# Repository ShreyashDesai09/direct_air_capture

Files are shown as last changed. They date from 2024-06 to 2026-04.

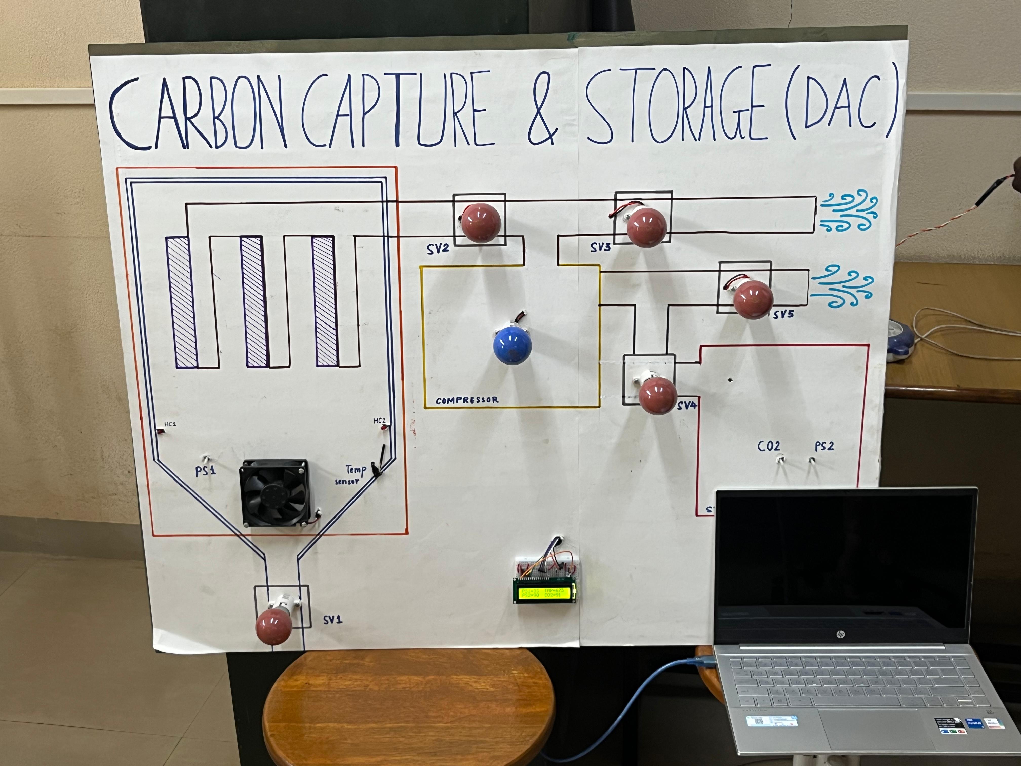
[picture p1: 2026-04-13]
Documents/Project.jpg

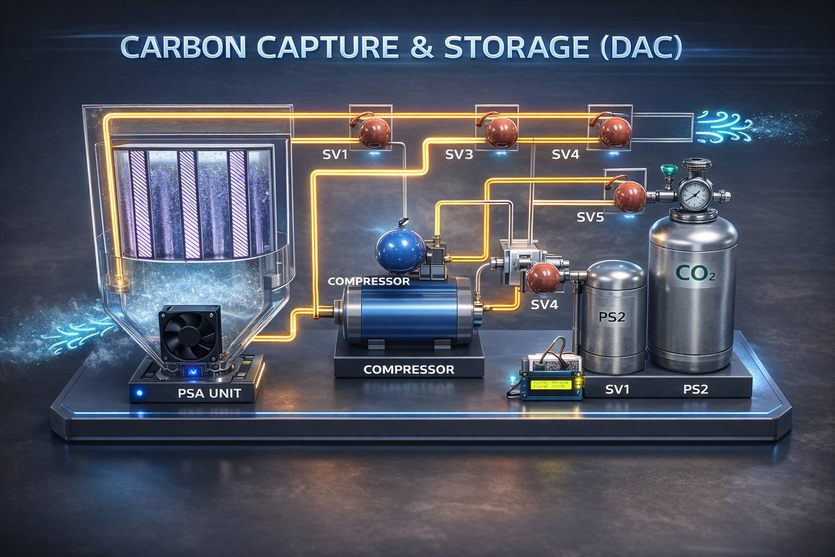
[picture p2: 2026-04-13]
Documents/Carbon Capture And Storage.png

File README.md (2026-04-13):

# Direct Air Capture Using Carbon Capture and Storage (CCS) technology

Arduino-based direct air capture system for extracting CO₂ from ambient air and storing it in a tank.  
🚀 A prototype showing hardware control, sensor monitoring, gas capture logic, and CAD-supported enclosure design.

Prototype schematic or mockup

## Project Summary

This repository contains the main Arduino sketch and supporting design assets for a direct air capture prototype. The system uses pressure, temperature, and CO₂ sensors to manage air flow, vacuum, heating, and storage stages.

The project demonstrates:

- 🧠 embedded Arduino control logic
- 🧪 analog sensor monitoring and serial debugging
- 💨 actuator control for fans, valves, heater, and vacuum
- 🛠️ CAD-based hardware design and assembly planning
- 📁 documentation-ready structure for prototyping

## What the System Does

- 🌡️ reads pressure, temperature, CO₂, and chamber pressure sensors
- 🌀 controls air flow, vacuum creation, heating, and storage
- 🧾 routes captured air through the sorbent/collection assembly
- 📡 displays live values on a 16x2 LCD and sends telemetry over Serial

## Key Files

- `Mega_Project_Final_Code.ino` — main Arduino sketch
- `README.md` — project overview and usage guide
- `Documents/3D Design/` — CAD parts for the sorbent panel and assembly

## Hardware Components

Typical components used in this prototype:

- 🧠 Arduino board (Uno, Nano, Mega, etc.)
- 🌿 CO₂ sensor module connected to `A2`
- 🧪 pressure sensors on `A0` and `A3`
- 🌡️ temperature sensor on `A1`
- 💨 fan or pump driver on pin `23`
- 🔧 solenoid valves `SV1`–`SV5` on pins `27`, `31`, `35`, `39`, `43`
- 🔋 vacuum compressor driver on pin `47`
- 🔌 heater control on pin `29`
- 🖥️ 16x2 LCD display wired via `LiquidCrystal` pins

## System Workflow

1. ⚙️ `setup()` initializes the LCD, serial port, sensors, and actuators.
2. 🔄 `loop()` cycles through:
   - `dis()` — read sensors and update LCD/Serial
   - `Air_Flow()` — open flow path and circulate air
   - `vacuum()` — close valves and engage vacuum
   - `heat()` — heat the chamber and monitor temperature
   - `store()` — manage final pressurization and storage
3. 🧭 Control decisions are based on measured analog values and safety thresholds.

## Operational Stages

- `Air_Flow()` — configures valves and fan to direct air through capture assembly
- `vacuum()` — closes flow valves, starts compressor, and creates negative pressure
- `heat()` — powers heater while monitoring temperature
- `store()` — manages final storage flow and chamber pressure

## 3D Design Assets

The `Documents/3D Design/` folder contains CAD files for the mechanical parts of the prototype, including:

- `sorbent panel.IGS`
- `I-section of sorbent panel.IGS`
- `100mm.CATPart`
- `150mm.CATPart`
- `left.CATPart`
- `right.CATPart`
- `Part1.CATPart`

These files can be used to visualize or manufacture the capture assembly and support structure.

## How to Use

1. 📝 Open `Mega_Project_Final_Code.ino` in Arduino IDE.
2. 🔌 Connect the Arduino to your PC.
3. 🔧 Wire the sensors and actuators according to the pin assignments in the sketch.
4. 🖥️ Select the correct board and COM port.
5. 📤 Upload the sketch.
6. 📟 Open Serial Monitor at `9600` baud and watch the LCD for live data.

## Recommended Enhancements

To make the project stronger and more portfolio-ready:

- 📊 add actual sensor mapping and calibration formulas
- 🧾 document the exact wiring and pin mapping
- 🧰 include a bill of materials (BOM)
- 📐 add a wiring diagram or schematic image
- 🎥 include photos or a demo video of the prototype
- 💾 add data logging or SD card export

## Notes

- ✅ Verify sensor wiring before powering the system.
- ⚠️ Calibrate the CO₂ sensor and temperature probe for accurate readings.
- 🔌 Ensure safe power, valve, and heater connections.

## License

This project is available for learning and experimentation. Add a license file if you want to define reuse terms explicitly.

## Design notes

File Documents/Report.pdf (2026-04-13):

A

Report on

## “Carbon Capture & Storage using Direct Air Capture Technology”

Submitted to

Shivaji University, Kolhapur

In Partial Fulfillment of therequirement for the degree of

Final Year of B. Tech

(ELECTRONIC AND TELECOMMUNICATION ENGINEERING)

Submitted by

PRN | Name of Student
2021000347 | Mr. Vaibhav Ramesh Kashid
2021000722 | Miss. Bhoomy Durgesh Lingras
2021000732 | Mr. Shreyash Amrut Desai
2122010119 | Mr. Archit Raghavendra Kulkarni

Under the guidance of

### Prof. A.R. Nigavekar

Submitted at

KOLHAPUR INSTITUTE OF TECHNOLOGY’S COLLEGE OFENGINEERING (AUTONOMOUS), KOLHAPUR

Year 2023-24

## CERTIFICATE

This is to certify that Mr. Vaibhav Ramesh Kashid (2021000347), Miss. Bhoomy Durgesh

Lingras (2021000722), Mr. Shreyash Amrut Desai (2021000732), Mr. Archit

Raghavendra Kulkarni (2122010119) have completed the Project Part-I on subject entitled

“Carbon Capture & Storage using Direct Air Capture Technology”, in the fulfillment of the

requirement for the award of Final Year (Electronics and Telecommunication Engineering) of

KIT’sCollege of Engineering, Kolhapur in the academic year 2023-24.

Date:

Place: Kolhapur

Prof. A.R. Nigavekar | External Examiner | Prof. Y. M. Patil
Project Guide | | Head ETC

Dr. M. B. Vanarotti

Director

## DECLARATION

We hereby declare that the Project entitled, “Carbon Capture & Storage using Direct Air Capture Technology” Phase-II project report submitted to KIT’s College of Engineering, Kolhapur, Maharashtra, INDIA in the partial fulfilment of the requirement for the “Electronics & Telecommunication” is a bona fide work carried out by us. The material contained in this Project has not been submitted to any University or Institution for the award of any degree.

Name of the Students:

Roll No. | Name | PRN No. | Signature
37 | Vaibhav Ramesh Kashid | 2021000347
38 | Bhoomy Durgesh Lingras | 2021000722
39 | Shreyash Amrut Desai | 2021000732
40 | Archit Raghavendra Kulkarni | 2122010119

Date:

Place: Kolhapur

## ACKNOWLEDGMENT

We would like to express our deep gratitude towards Prof. A.R. Nigavekarand Dr. Y.M. Patil

Head of Department for their constant encouragement and guidance. Their support and

cooperation throughout the project work has been ofimmense help to us.

We express our sincere thanks to all the teaching and non-teaching staff and all those who

have directly or indirectly helped in making the project a success.

PRN No. | Name of Student
2021000347 | Mr. Vaibhav Ramesh Kashid
2021000722 | Miss. Bhoomy Durgesh Lingras
2021000732 | Mr. Shreyash Amrut Desai
2122010119 | Mr. Archit Raghavendra Kulkarni

# Contents

6.3.2. Explanation of the Design Considerations for Efficiency, Scalability, and Cost-Effectiveness ...... 18

### 1. ABSTRACT

Addressing the pressing global challenge of rising atmospheric carbon dioxide

(CO2) levels demands innovative solutions to achieve climate stability. Current

reduction efforts fall short of meeting necessary targets, underscoring the urgency

for effective interventions. Direct Air Capture (DAC) technology emerges as a

promising avenue, yet it grapples with hurdles related to cost, energy efficiency,

and scalability. The crux of this mega project involves optimizing room-scale

DAC technology through an open-source framework, leveraging crowd-sourced

ideas, and a collaborative open data set for iterative enhancements. With a keen

understanding of the potential consequences of unchecked CO2 levels, the

overarching objective is to elevate carbon dioxide capture efficiency, champion

sustainability, and decisively combat climate change. This mega project stands

poised to catalyze transformative advancements, galvanizing collective efforts

toward a more sustainable future.

### 2. INTRODUCTION

### 2.1. CCS Technology:

Carbon Capture and Storage (CCS) is a critical technology aimed at reducing greenhouse gas

emissions, particularly carbon dioxide (CO2), from industrial processes and power generation. The

Intergovernmental Panel on Climate Change (IPCC) highlights CCS as one of the key strategies to

limit global warming to well below 2°C. The process involves capturing CO2 emissionsfrom

point sources such as power plants or industrial facilities, transporting it to storage sites, and

securely storing it underground in geological formations, preventing it from entering the

atmosphere and contributing to climate change.

### 2.2. Background and Significance of Carbon Capture & Storage:

The concept of CCS has gained significant attention in recent decades due to theurgent need to

mitigate climate change and reduce CO2 emissions. The burning of fossil fuels for energy

production is a major contributor to CO2 emissions,and CCS offers a way to capture and store

this CO2 before it reaches the atmosphere. By preventing CO2 emissions from entering the

atmosphere, CCScan help to achieve climate targets and transition to a low-carbon economy while

maintaining reliable energy supplies from fossil fuels during the transitionperiod.

### 2.3. Overview of Direct Air Capture (DAC) Technology:

Direct Air Capture (DAC) technology is an innovative approach to capturing CO2 directly from the

atmosphere, regardless of the source of emissions. Unlike traditional CCS, which captures CO2

from point sources, DAC systems can be deployed anywhere, making them versatile and scalable.

DAC technology typically involves large-scale chemical processes or sorbent materials that

selectively capture CO2 from ambient air. Once captured, the CO2 can be stored underground or

utilized in various industrial processes, such as enhanced oil recovery or production of synthetic

fuels.

### 2.4. DAC Importance:

DAC technology plays a crucial role in complementing traditional CCS methods by offering a

means to address emissions from sources that are difficult to capture, such as transportation and

agriculture. It provides a pathway to achieve negative emissions, where more CO2 is removed from

the atmosphere than emitted, helping to offset remaining emissions from sectors that are

challenging to decarbonize. DAC can also be integrated with renewable energy sources to create

carbon-negative energy systems, further reducing the carbon footprint of human activities.

### 2.5. Project Objectives:

The primary objective of this project is to investigate the feasibility and effectiveness of Direct Air

Capture (DAC) technology for carbon capture and storage (CCS) applications. Specifically, the

project aims to:

- Assess the technical and economic viability of DAC systems for capturing CO2 from the

atmosphere.

- Develop and optimize a DAC system prototype or model for carbon capture.
- Evaluate the environmental benefits and potential scalability of DAC technology for mitigating

climate change.

- Explore potential challenges and opportunities associated with the implementation of DAC

technology at scale.

- Provide recommendations for policy-makers, industry stakeholders, andresearchers on the role of

DAC in achieving climate goals and transitioning to a low-carbon future.

### 3. REVIEW OF LITERATURE

- By referring to paper [1], we understood about a technology assessment of DAC with a

focus on the chemical processes involved. It discusses the feasibility and challenges

associated with DAC technology.

- By referring to paper [2], we understood that this study explores the optimization of a

specific DAC system utilizing a two-loop hydroxide carbonate process. It discusses

improvements in efficiency and performance through countercurrent air flow.

- By referring to this research article [3], we got to know the transition of DAC technology

from laboratory-scale experiments to demonstration projects. It highlights advancements

made in scaling up DAC systems.

- After going through this review paper [4], we got to know the relevance of CCS

technologies, including DAC, in mitigating CO2 emissions. It addresses the challenges and

opportunities specific to the Indian context.

- The review presented in reference [5] provides an overview of various CO2 capture

technologies, including DAC, highlighting their challenges and potential solutions. It

discusses the technical aspects and economic considerations of CCS.

- After referring to the article of reference [6], we understood the cost implications of CCS

technologies, including DAC, emphasizing the importance of cost reduction strategies for

widespread deployment. It discusses factors influencing the cost of CO2 capture and

storage.

- By referring to this article [7], we got to know the state-of-the-art DAC technologies,

their mechanisms, and potential applications. It explores the scientific and engineering

aspects of DAC.

- By referring to paper [8], we understood about different solvents used for CO2absorption

from flue gas, a process relevant to DAC technology. It discusses the properties and

performance of various solvents and their implications for CO2 capture efficiency.

### 3.1. Review of Existing Literature on CCS and DAC Technology

Carbon Capture and Storage (CCS) and Direct Air Capture (DAC) technologies have gained

significant attention in recent years due to their potential to mitigate carbon dioxide (CO2)

emissions and combat climate change. A thorough review ofexisting literature reveals a wealth of

research papers, journals, and reports focusedon various aspects of CCS and DAC technology.

Numerous studies have explored the technical feasibility, economic viability, and environmental

implications of CCS and DAC implementations. These investigations encompass a wide range of

topics, including capture technologies, storage methods, cost analyses, policy frameworks, and

environmental impacts.

### 3.2. Summary of Key Findings

Key findings from relevant literature emphasize the following points:

1. Technical Feasibility: Research indicates that both CCS and DAC technologies are technically

feasible for capturing CO2 emissions from various sources, including industrial processes and

the atmosphere. Advances in capture techniques, such as solvent-based absorption and solid

adsorption, have demonstrated high CO2 capture efficiencies.

2. Economic Viability: While CCS and DAC technologies have historically faced economic

challenges, recent studies suggest that cost reductions are achievable through technological

innovation, scale-up, and policy support. Cost analyses highlight the importance of considering

factors such as energy requirements, capital investments, and operational expenses in

evaluating the economic feasibility of CCS and DAC projects.

3. Environmental Implications: Assessments of the environmental impacts associated with CCS

and DAC implementations underscore the importance of lifecycle assessments and

sustainability considerations. While CCS offers the potential to reduce CO2 emissions from

stationary sources, concerns exist regarding leakage risks and the long-term integrity of storage

reservoirs. Similarly, DAC technologies raise questions about energy consumption, land use,

and the potential for unintended environmentalconsequences.

4. Policy and Regulatory Frameworks: The development of supportive policy frameworks and

regulatory incentives is identified as a crucial enabler for the deployment of CCS and DAC

technologies at scale. Initiatives such as carbon pricing mechanisms, tax credits, and research

funding play significant roles in driving innovation and investment in carbon capture and

storage initiatives.

### 3.3. Discussion on the Current State of DAC Technology, Challenges, and

Opportunities

Despite significant progress in research and development, several challenges persist in the

advancement and widespread adoption of DAC technology:

1. Energy Intensity: DAC technologies currently exhibit high energy requirements, primarily

due to the need for air circulation, CO2 capture, and regeneration processes. Addressing the

energy intensity of DAC systems is critical to improving efficiency and reducing operational

costs.

### 2. Cost Competitiveness: While cost reductions have been achieved in recent years, DAC

remains more expensive than conventional carbon abatement strategies such as emission

reductions and renewable energy deployment. Enhancing cost competitiveness through

technological innovation and economies of scale is essential to unlocking the full potential of

DAC as a climate mitigation tool.

### 3. Scale-Up and Deployment: Scaling up DAC technology from laboratory prototypes to

commercial-scale installations presents logistical and infrastructural challenges. Deploying

DAC facilities at the necessary scale requires significant investment, infrastructure

development, and regulatory approvals.

4. Carbon Utilization and Storage: Utilizing captured CO2 for beneficial purposes, such as

enhanced oil recovery or the production of synthetic fuels, can enhance the economic viability

of DAC projects. However, ensuring the permanent and secure storage of captured CO2

remains a critical consideration for long-term carbon management.

Despite these challenges, DAC technology offers several opportunities for addressing global

carbon emissions:

1. Negative Emissions: DAC provides a pathway for achieving negative emissions by actively

removing CO2 from the atmosphere. Integrating DAC with carbon utilization and storage

strategies can enable net-negative emissions, helping to offset residual emissions from hard-to-

abate sectors.

2. Flexibility and Location Independence: Unlike traditional carbon capture technologies,

DAC systems are not limited by the proximity of emission sources, offering flexibility in

deployment and location independence. This characteristic makes DAC particularly suitable

for capturing emissions from dispersed sources and addressing CO2 emissions from sectors such as aviation and agriculture.

3. Technological Innovation: Continued research and development efforts are driving

technological innovation in DAC, leading to efficiency improvements, cost reductions, and

novel capture approaches. Advances in materials science, engineering design, and process

optimization hold promise for further enhancing the performance and scalability of DAC

systems.

4. Climate Resilience: DAC technology offers potential benefits for climate resilience by

providing a means to actively remove CO2 from the atmosphere, thereby helping to mitigate

the impacts of climate change. As part of a comprehensive climate mitigation strategy, DAC

can contribute to achieving ambitious emissions reduction targets and safeguarding vulnerable

ecosystems.

### 4. Problem Definition

Addressing the critical threat posed by rising atmospheric carbondioxide (CO2) levels to

global climate stability requires an innovative approach. Current efforts to reduce CO2

emissions fall short, necessitating the optimization of Direct Air Capture (DAC)

technology. However, DAC faces challenges in cost-effectiveness, energy efficiency, and

scalability. The goal is to improve room-scale DAC systems through an open-source

approach, using crowd-sourced ideas and open data for iterative enhancements. By

boosting CO2 capture efficiency, this initiative aims to promote sustainability and combat

climate change effectively. The focus is on collaborative innovation to refine DAC

technology for a more resilient and eco-friendly future.

### 5. Methodology

The objective of this project is to design, develop, and implement an innovative Direct Air Capture (DAC) system that addresses the urgent need for scalable and sustainable carbon removal solutions. This project aims to contribute to the mitigation of climate change by achieving the following key objectives:

### 5.1. Development of an Efficient DAC Technology:

- Design and construct a state-of-the-art DAC system that maximizes CO2 capture efficiency while minimizing energy consumption.
- Investigate and integrate advanced capture materials and methods, such as chemical sorbents, adsorption technologies,and electrochemical approaches, to enhance DAC systemperformance.

### 5.2. Scalability and Cost Reduction:

- Engineer the DAC system with scalability in mind, ensuring it can be deployed at a sizeable capacity to have a meaningful impact on CO2 removal.
- Explore innovative engineering and manufacturing processes to reduce the overall cost of DAC technology, making it economically viable for widespread deployment.

### 5.3. Carbon Utilization and Storage:

- Investigate opportunities for the utilization of captured CO2, such as in the production of carbon-neutral fuels, construction materials, or other value-added products.
- Implement effective and environmentally responsible strategies for the secure and long-term storage of captured CO2, including geologic storage and utilization in carbon-negative applications.

### 5.4. Environmental Sustainability:

- Conduct a comprehensive life cycle assessment (LCA) to evaluate the environmental footprint of the DAC system, taking into account emissions associated with construction, operation, and decommissioning.
- Develop strategies to minimize water usage, land footprint, and other potential environmental impacts associated with DAC deployment.

### 6. System Design

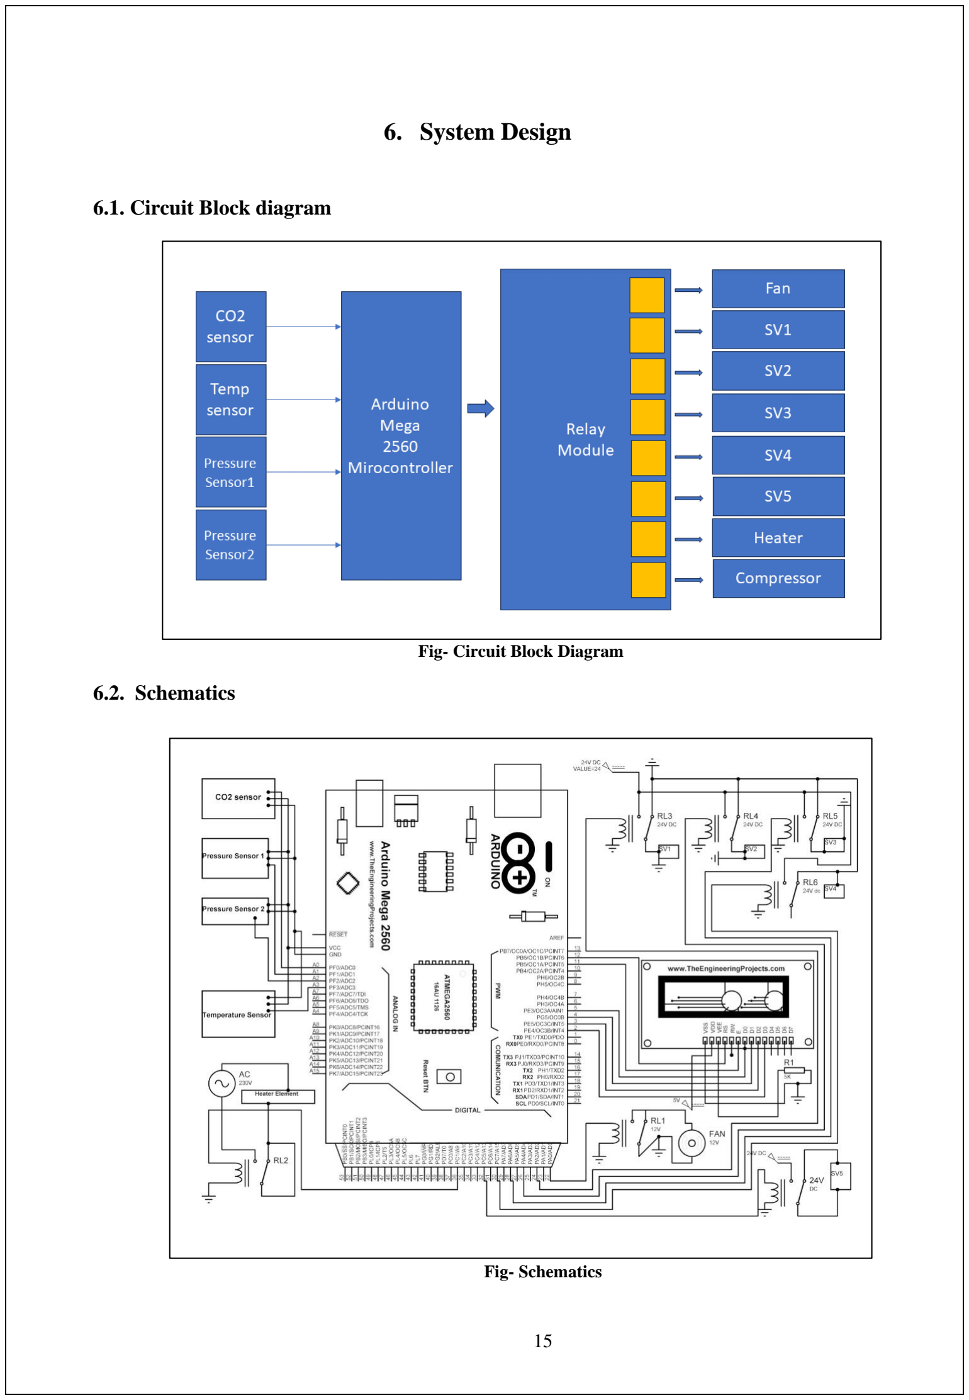
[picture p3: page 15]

### 6.1. Circuit Block diagram

Fig- Circuit Block Diagram

### 6.2. Schematics

Fig- Schematics

### 6.3. DAC System, Including Components and Subsystems

The Direct Air Capture (DAC) system is designed to capture carbon dioxide (CO2) directly from the

atmosphere using a combination of capture, separation, and storage processes. The system comprises

several key components and subsystems, each playing a critical role in the overall functionality and

performance of the DAC system:

- Air Intake System: The DAC system begins with an air intake system responsible for drawing ambient air into the capture unit. This system typically consists of intake vents or fans to facilitate the flow of air into the capture chamber.
- Capture Chamber: The capture chamber is the primary component where CO2 is captured from the ambient air. Various capture technologies can be employed, including chemical absorption, adsorption onto solid sorbents, or membrane separation. The choice of capture technology depends on factors such as efficiency, selectivity, and scalability.
- CO2 Separation Unit: Following capture, the CO2 must be separated from the capture medium for storage or utilization. Separation processes may involve desorption, regeneration, or purification steps to isolate the captured CO2 from the capture medium. Common separation techniques include thermal regeneration, pressure swing adsorption, or cryogenic distillation.
- CO2 Storage and Utilization: The separated CO2 can be stored underground in geological formations, utilized for enhanced oil recovery, or converted into valuable products such as synthetic fuels or building materials. The design of the storage and utilization subsystems depends on the intended application and regulatory requirements.
- Energy and Heat Management: The DAC system requires energy inputs for air circulation, capture, separation, and regeneration processes. Efficient energy management strategies, such as heat recovery, process integration, and renewable energy integration, are essential for minimizing energy consumption and enhancing system efficiency.
- Monitoring and Control System: To ensure optimal performance and operational safety, the DAC system incorporates monitoring and control systems for real-time monitoring of key parameters, process optimization, and fault detection. Sensors, actuators, and control algorithms are deployed to maintain system stability and reliability.

### 6.3.1. Main Block Diagram

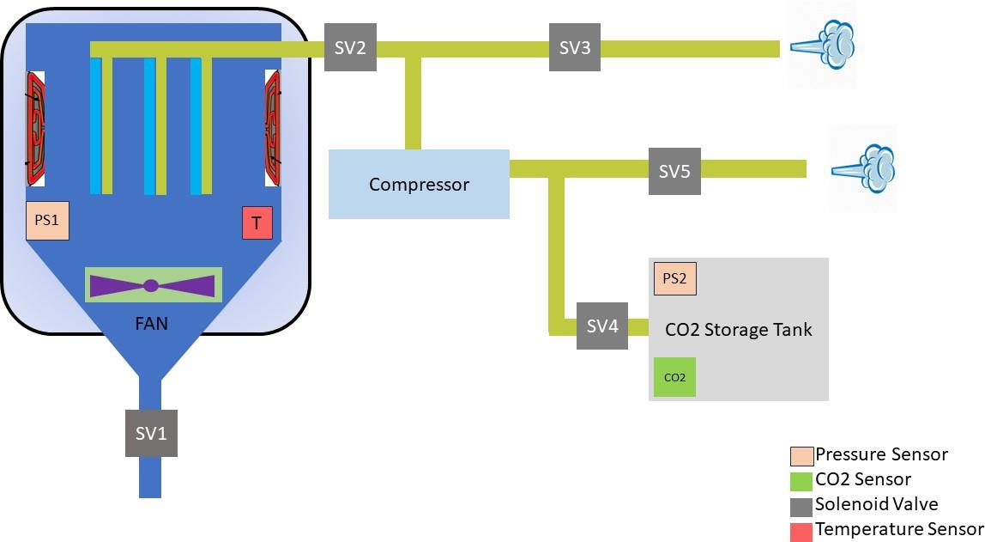
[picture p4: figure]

Fig. Carbon Capture and Storage using DAC Technology

The operation of the DAC system can be illustrated through schematic diagrams or flowcharts,

outlining the sequence of processes and interactions between system components. A simplified

flowchart of the DAC system operation include the following steps:

1. Air Intake: Ambient air is drawn into the capture chamber through intake vents or fans.
2. CO2 Capture: CO2 is captured from the incoming air using a capture medium or technology (e.g., chemical absorption, adsorption).
3. CO2 Separation: The captured CO2 is separated from the capture mediumthrough desorption or regeneration processes.
4. Storage/Utilization: The separated CO2 is either stored underground or utilized for various applications such as enhanced oil recovery or synthetic fuel production.

### 5. Energy Management: Energy inputs are managed efficiently to power the operation of the

DAC system, with considerations for energy recovery andrenewable energy integration.

6. Monitoring and Control: The system is monitored in real-time, and controlalgorithms adjust operating parameters to optimize performance and ensure safe operation.

### 6.3.2. Explanation of the Design Considerations for Efficiency, Scalability, and Cost-

Effectiveness

Efficiency, scalability, and cost-effectiveness are critical design considerations forthe DAC system:

1. Efficiency: The efficiency of the DAC system is influenced by factors such as capture efficiency,

energy consumption, and process integration. Design considerations focus on optimizing capture and

separation processes, minimizing energy requirements, and maximizing the utilization of captured

CO2.

2. Scalability: The scalability of the DAC system is essential for deploying large-scale installations

capable of capturing significant quantities of CO2. Design considerations include modularization,

equipment sizing, and process optimization to facilitate the expansion of the system while

maintaining performance and reliability.

3. Cost-Effectiveness: Achieving cost-effectiveness involves balancing capital investments, operational

expenses, and lifecycle costs. Design considerations include the selection of cost-competitive

materials and technologies, process optimization for resource efficiency, and the integration of

renewable energy sources to reduce operating costs.

### 7. Hardware and Software Required

### 7.1 HARDWARE

### 1. Microcontroller Board: -

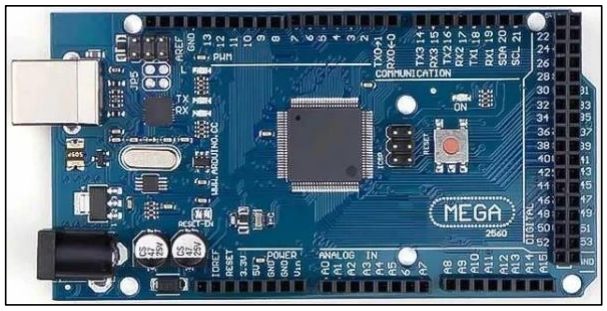
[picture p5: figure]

The Arduino Mega microcontroller board was chosen due to several key reasons:

- Extensive I/O Capabilities: The Arduino Mega offers a large number of digital and analog

input/output pins, making it suitable for connecting and controlling multiple sensors,

actuators, and peripherals simultaneously. This is crucial for a project like DAC technology,

which may involve numerous sensors for environmental monitoring, data acquisition, and

control purposes.

- Processing Power: With its ATmega2560 processor running at 16 MHz and ample flash

memory (256 KB), the Arduino Mega provides sufficient processing power and storage

capacity to handle complex algorithms, data processing tasks, and control logic required in

DAC systems. This is important for real-time monitoring, control, and decision-making

processes within the system.

- Compatibility and Community Support: Arduino boards, including the Mega, benefit from

a vast community of developers, makers, and enthusiasts. This ensures a wide range of

compatible libraries, example codes, tutorials, and community forums where you can seek

assistance, share ideas, and troubleshoot issues encountered during the project. This support

network can significantly expedite development and reduce implementation challenges.

- Expandability and Modularity: The Arduino Mega's modular design allows for easy

expansion through shields and modules, providing flexibility to add additional functionality

or interface with external devices as needed for your DAC technology project. This

scalability is advantageous for future upgrades or modifications to the system.

- Cost-Effectiveness: Compared to some other microcontroller boards with similar

capabilities, the Arduino Mega offers a balance of features, performance, and affordability.

This makes it a cost-effective choice for projects with demanding I/O requirements and

processing tasks, such as Direct Air Capture technology development.

Specifications:

- Microcontroller: ATmega2560
- Operating Voltage: 5V
- Input Voltage (recommended): 7-12V
- Input Voltage (limits): 6-20V
- Digital I/O Pins: 54 (of which 15 provide PWM output)
- Analog Input Pins: 16
- DC Current per I/O Pin: 20 mA
- DC Current for 3.3V Pin: 50 mA
- Flash Memory: 256 KB (8 KB used by bootloader)
- SRAM: 8 KB
- EEPROM: 4 KB
- Clock Speed: 16 MHz

### 2. Pressure Sensor: -

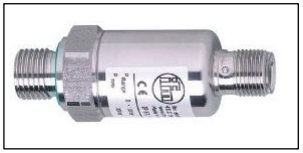
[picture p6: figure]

The PT9544 pressure sensor is used due to its suitability for measuring pressure in the context of

atmospheric conditions and vacuum systems.

- Pressure Range: The PT9544 sensor is designed to measure a wide pressure range, typically

from atmospheric pressure down to vacuum levels. This range is relevant for DAC

technology, where pressure measurements may span from ambient air pressure to lower

pressures within the capture and storage systems.

- Accuracy and Precision: The PT9544 sensor offers good accuracy and precision in pressure

measurements, which is essential for capturing reliable data in DAC processes. Accurate

pressure readings are crucial for monitoring and controlling the operation of air capture units,

ensuring optimal performance and efficiency.

- Compact and Versatile: The compact size of the PT9544 sensor makes it easy to integrate

into your DAC system without occupying excessive space. Its versatility allows for flexible

installation options, enabling precise pressure measurements at key points within the capture

and storage infrastructure.

- Reliability and Durability: The PT9544 sensor is designed for reliable long-term

performance, with features that enhance durability in varying environmental conditions. This

reliability is crucial for continuous and accurate pressure monitoring in DAC systems,

contributing to the overall effectiveness and stability of the technology.

Specifications:

- Pressure Range: Typically, 0 to 10 bar (other pressure ranges may be available)
- Output Signal: Analog (0-10V or 4-20 mA) (±0.5% of Full Scale (FS))
- Supply Voltage: 10-30 VDC
- Operating Temperature: -25°C to 85°C
- Electrical Connection: M12 connector or cable
- Material: Stainless steel (housing)

- Protection Rating: IP65/IP67 (depending on the variant)

### 3. CO2 Sensor: -

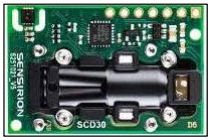
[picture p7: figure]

The Sensirion Non-Dispersive Infrared (NDIR) CO2 sensor was selected for several compelling

reasons:

- Accurate CO2 Measurement: NDIR sensors are known for their high accuracy in

measuring CO2 concentrations. This is critical in DAC systems, where precise monitoring of

CO2 levels in the air is essential for capturing and storing carbon dioxide effectively.

- Wide Measurement Range: The Sensirion NDIR CO2 sensor typically offers a wide

measurement range, allowing it to accurately detect CO2 concentrations ranging from

ambient levels to higher concentrations encountered in DAC processes.

- Stability and Long-Term Performance: NDIR technology provides stable and reliable CO2

measurements over extended periods, making it suitable for continuous monitoring and

control applications in DAC systems. Consistent performance is vital for maintaining the

efficiency and effectiveness of CO2 capture and storage processes.

- Low Power Consumption: Many NDIR CO2 sensors, including those from Sensirion, are

designed to operate with low power consumption. This is advantageous for energy-efficient

operation, especially in remote or off-grid DAC installations where power conservation is a

priority.

Specifications:

- Measurement Principle: Non-Dispersive Infrared (NDIR)
- Carbon Dioxide (CO2) Measurement Range: 0-40,000 parts per million (ppm)
- Accuracy: ± (30 ppm + 3% of measured value) within 400-10,000 ppm
- Response Time: <2 minutes (for 63% step change)
- Temperature Range (Operating): 0°C to 50°C
- Humidity Range (Operating): 0% to 100% RH (non-condensing)
- Supply Voltage: 3.3 V to 5.5 V
- Communication Interface: I2C (up to 400 kHz) and UART (up to 115200 bps)

- Dimensions: 35.6 mm x 23.3 mm x 3 mm (L x W x H)
- Digital Output Resolution: 16-bit
- Power Consumption (Average): 19 mA @ 3.3 V (continuous operation)
- Warm-up Time: <30 seconds

### 4. Molecular Sieves: -

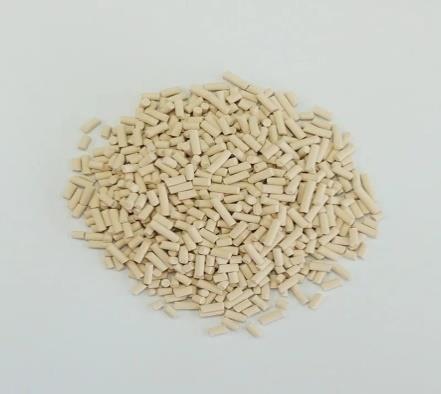
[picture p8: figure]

Molecular sieves specifically 13X taken into consideration due to its various abilities.

- Selective Adsorption: Molecular sieves are designed to selectively adsorb molecules of

specific sizes. 13X sieves are known for their ability to selectively adsorb CO2 from air while

allowing other gases like nitrogen and oxygen to pass through.

- High Capacity: 13X molecular sieves have a high CO2 adsorption capacity, meaning they

can capture a significant amount of CO2 per unit weight or volume of the sieves. This high

capacity is crucial for efficient DAC systems.

- Regenerability: Molecular sieves can be regenerated by desorbing the captured CO2,

allowing them to be reused multiple times. This makes them cost-effective and

environmentally friendly compared to single-use adsorbents.

- Stability: 13X molecular sieves are stable under a wide range of operating conditions,

including varying temperatures and pressures commonly encountered in DAC systems.

- Commercial Availability: These sieves are commercially available in large quantities,

making them readily accessible for DAC projects at scale.

Specifications:

- Type: 13X (Type X) molecular sieves
- Pellet Diameter: 1.6 mm (other diameters may also be available)
- Adsorbate: Primarily used for adsorption of CO2 from air

- Pore Size: Approximately 10 angstroms (1 nanometer), suitable for capturing CO2

molecules while allowing smaller molecules like nitrogen and oxygen to pass through

- Surface Area: Typically ranges from 600 to 800 square meters per gram (m²/g), providing

a large surface area for CO2 adsorption

- Adsorption Capacity: Can adsorb a significant amount of CO2 per unit weight of

molecular sieves, depending on the specific conditions and activation level

### 5. Temperature sensor: -

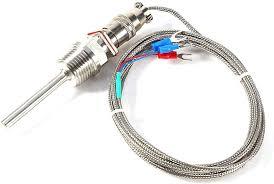
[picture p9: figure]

PT100 sensors, also known as platinum resistance temperature detectors (RTDs), are commonly

used in projects involving Direct Air Capture (DAC) technology for several reasons:

- Accuracy: PT100 sensors offer high accuracy in temperature measurement, which is crucial

for monitoring and controlling temperature-sensitive processes in DAC systems. Precise

temperature control is often necessary for optimal performance and efficiency.

- Stability: PT100 sensors are known for their stability and low drift over time. This ensures

that temperature measurements remain reliable and consistent throughout the operation of the

DAC system, leading to consistent process performance.

- Linear Response: PT100 sensors exhibit a linear response to temperature changes, making it

easier to calibrate and interpret temperature readings accurately. This linear response is

beneficial for maintaining specific temperature setpoints in DAC processes.

- Wide Temperature Range: PT100 sensors can operate in a wide temperature range,

including the elevated temperatures that may be encountered in DAC systems during certain

processes like CO2 desorption or regeneration of adsorbents.

- Compatibility: PT100 sensors are compatible with standard measurement and control

systems commonly used in industrial settings, making integration into DAC technology

projects relatively straightforward.

- Industry Standard: PT100 sensors are widely used and well-established in various

industries for temperature sensing applications due to their accuracy, stability, and reliability.

This makes them a preferred choice for many DAC technology projects where precise

temperature control and monitoring are essential.

Specifications:

The specifications of a PT100 temperature sensor, which is a type of platinum resistance

temperature detector (RTD), typically include the following:

- Type: PT100 (Platinum RTD)
- Temperature Range: Standard PT100 sensors can measure temperatures from -200°C to

850°C (-328°F to 1562°F). Extended range PT100 sensors may have wider temperature

measurement capabilities.

- Accuracy: PT100 sensors offer high accuracy, often within ±0.1°C to ±1°C depending on

the grade and calibration.

- Resistance at 0°C: The resistance of a PT100 sensor at 0°C is 100 ohms (hence the name

PT100), which increases linearly with temperature changes.

- Temperature Coefficient: The temperature coefficient of resistance for PT100 sensors is

approximately 0.00385 ohms/ohm/°C, which is used in calculations to convert resistance

changes into temperature readings.

- Construction: PT100 sensors are typically made of platinum wire wound around a

ceramic or glass core to form a resistance element.

- Response Time: PT100 sensors have a relatively fast response time, typically within a

few seconds for most applications.

### 6. Solenoid Valve:-

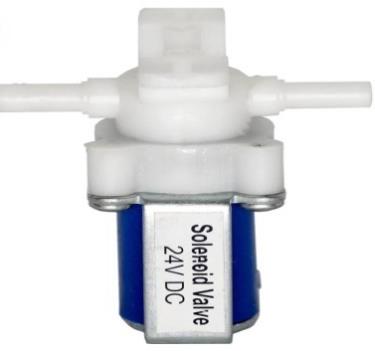
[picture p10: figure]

Solenoid valves operating at 24V DC:

- Controlled Gas Flow: Solenoid valves are used to control the flow of gases, such as air and

CO2, within DAC systems. They allow for precise regulation of gas flow rates, which is

critical for maintaining optimal process conditions during CO2 capture, release, and storage

phases.

- Automation: The use of solenoid valves allows for automation of gas flow control, reducing

the need for manual adjustments. This automation improves system efficiency, consistency,

and reliability, as it can be integrated into control systems and programmed to operate based

on predefined parameters.

- Response Time: Solenoid valves have fast response times, enabling rapid opening and

closing actions. This quick response is beneficial for immediate adjustments to gas flow rates,

especially during dynamic process conditions or in response to system requirements.

- Compatibility: Solenoid valves operating at 24V DC are compatible with common power

sources and control systems used in industrial settings, making them easy to integrate into

DAC technology projects.

Specifications:

- Voltage: 24V DC (Direct Current)
- Valve Type: Normally Closed (NC), meaning the valve is closed when no power is applied to

the solenoid coil and opens when energized.

- Operating Pressure Range: Typically, solenoid valves for industrial use can handle pressures

ranging from 0 to several hundred pounds per square inch (psi) depending on the specific

model and application requirements.

- Flow Rate: Common flow rates range from a few GPM (gallons per minute) to several tens of

GPM.

- Valve Size: Solenoid valves come in various sizes, such as 1/4-inch, 1/2-inch, 3/4 inch, and 1

inch, among others. The valve size is selected based on the required flow capacity of the

system.

### 7.2. SOFTWARE

### 7.2.1. SOLIDWORKS

CAD (computer aided design) design is used in almost every industry, in projects as wide-ranging

as landscape design, bridge construction, office building design and movieanimation. With 2D or

3D CAD programs, you can perform a variety of tasks: you can create a 3D model of a design,

apply material and light effects, and document the designwith dimensions and other annotations.

With features like point clouds, you can add real-life context to your drawings to create a digital

twin or recreate physical objects in your designs. It helps users create designs in either 2D or 3D to

visualize construction, and enables the development, modification, and optimization of the design

process. Thishelps designers make more accurate representations and modify them more easily to

improve design quality.

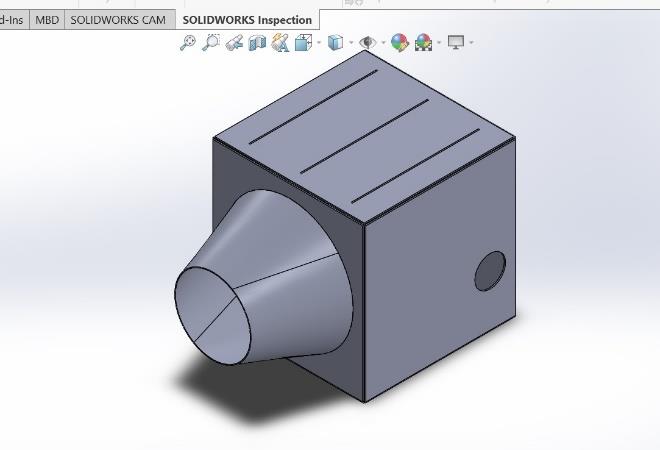
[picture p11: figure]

### 7.2.2. Arduino IDE

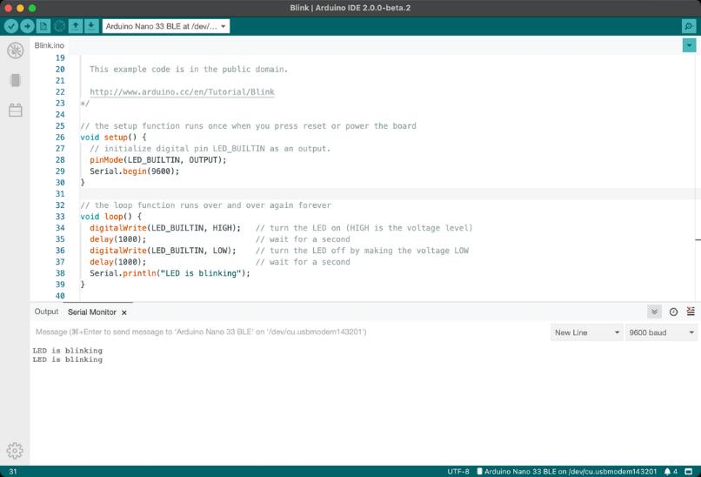
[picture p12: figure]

The Arduino IDE (Integrated Development Environment) is a software platform used for

programming Arduino boards. Here's some key information about it:

1. Open Source: Arduino IDE is an open-source platform, which means its source code is freely

available for modification and distribution.

2. Cross-Platform Compatibility: It's compatible with Windows, Mac OS X, and Linux operating

systems, making it accessible to a wide range of users.

### 3. Programming Language: Arduino IDE primarily uses a simplified version of C++ for

programming Arduino boards. It abstracts away a lot of the complexities of traditional C++

programming, making it more accessible to beginners.

4. Code Editor: It provides a code editor where users can write, edit, and save their Arduino

sketches (programs). The editor includes features like syntax highlighting, auto-indentation, and

code completion to aid in writing code.

5. Library Management: Arduino IDE comes with a library manager that allows users to easily

install and manage libraries, which are collections of pre-written code that extend the functionality of

Arduino boards.

6. Board Manager: It includes a board manager that enables users to install support for different

Arduino boards, including official Arduino boards as well as third-party boards.

7. Serial Monitor: Arduino IDE has a built-in serial monitor tool that allows users to communicate

with their Arduino board over a serial connection. This is useful for debugging and monitoring the

output of their sketches.

8. Upload Tool: Arduino IDE provides a simple interface for uploading sketches to Arduino boards

via USB or other communication interfaces supported by the board.

9. Community Support: There's a large and active community of Arduino users who contribute

tutorials, libraries, and troubleshooting advice, making it easier for beginners to get started and for

experienced users to find solutions to their problems.

10. Extensibility: Arduino IDE can be extended with plugins and additional tools to enhance its

functionality and cater to specific needs.

### 8. Procedure

### 1. Inserting Molecules in Chamber

The chamber consists of three separate sorbent panels. Each having capacity to hold 500 gm of 13x

molecular sieves.

### 2. Air Flow

Turn on the fan and vacuum pump. Open the solenoid valaves 1, 2 and 3 and close the solenoid

valve 4 and 5. This will allow the air to pass through the molecules.

### 3. Creating vacuum in chamber

Now turn off the fan and Solenoid valve 1. At normal temperature sorbent molecules will adsorb

CO2from air and remaining contents from air will be sucked through vacuum pump and thrown out

through Solenoid Valve 5. This process will go on until certain limit of vacuum pressure is reached.

This pressure is measured by PT9544 pressure sensor. After that vacuum pump, Solenoid Valve 2

and 5 will become off.

### 4. Giving heat to the Molecular Sieves

Now Heat the molecules at constant temperature for 75o± 4oC with help of heating element

Nichrome Wire. Here we have programmed microcontroller such that it acts like a thermostat i.e

temperature exceeds 75o it will switch off the supply to Nichrome Wire and if temperature goes

below 75oC it will ON the supply to Nichrome Wire. This process will go on for 30 Minutes.

### 5. Storing CO2 in Tank and displaying it’s Concentration

Now open the Solenoid Valve 2 and 4 and switch on the Vacuum Pump to store the relased CO2

from molecules into tank. Once the specified level is reached Solenoid Valve 2 and 4 and Vacuum

pump will become OFF. Then concentration of CO2in ppm will be displayed on 16x2 LCD

Display.

### 9. CONCLUSION

The conclusion highlights the potential of Direct Air Capture (DAC) integrated with

Carbon Capture and Storage (CCS) to combat CO2 emissions. It emphasizes DAC's

scalability, efficiency, and technical aspects like 13x molecular sieves, advanced materials,

and energy-efficient operations. Collaboration is crucial for further research, cost

reduction, and global deployment of CCS DAC solutions, contributing to a sustainable,

carbon-neutral future.

### 10. REFERENCES

1. "Direct Air Capture of CO2 with Chemicals: A Technology Assessment for the APS Panel onPublic Affairs"
- Authors: Kurt Zenz House, Christopher H. House
- Published in: Physics Today
- Source: https://physicstoday.scitation.org/doi/10.1063/PT.3.3417
2. "Direct Air Capture of CO2 with Chemicals: Optimization of a Two-Loop Hydroxide CarbonateSystem Using a Countercurrent Air Flow"
- Authors: Paul M. Mathews, Kurt Zenz House, Christopher H. House
- Published in: Industrial & Engineering Chemistry Research
- Source: https://pubs.acs.org/doi/10/1021/ie301443
3. "Air Capture of CO2 by Chemical Absorption: From Lab to Demonstration Scale"
- Authors: David W. Keith, Geoffrey Holmes, David St. Angelo, Kenton Heidel
- Published in: AIChE Journal
- Source: https://onlinelibrary.wiley.com/doi/abs/10.1002/aic.10333
4. "Review of Carbon Dioxide Capture and Storage with Relevance to the Indian Power Sector"
- Authors: Amulya K. N. Reddy, Sujata K. Prakash, Sudhakar S. Patwardhan
- Published in: Energy for Sustainable Development
- Source: https://www.sciencedirect.com/science/article/pii/S0973082614000091
5. "Review of CO2 Capture Technologies and Challenges"
- Authors: Zhen Zhu, Alan J. Hunt
- Published in: Chemical Engineering Research and Design
- Source: https://www.sciencedirect.com/science/article/pii/S0263876213001692
6. "The Cost of CO2 Capture and Storage"
- Authors: Joule A. Bergerson, Brad Stelfox
- Published in: International Journal of Greenhouse Gas Control
- Source: https://www.sciencedirect.com/science/article/pii/S1750583612001809
7. "Direct Capture of CO2 from Ambient Air"
- Authors: David W. Keith
- Published in: Chemical Reviews
- Source: https://pubs.acs.org/doi/10.1021/acs.chemrev.8b00799
8. "Review of Solvents for CO2 Absorption from Flue Gas"
- Authors: Paitoon Tontiwachwuthikul, Apichat Imyen
- Published in: International Journal of Greenhouse Gas Control
- Source: https://www.sciencedirect.com/science/article/pii/S1750583612000018

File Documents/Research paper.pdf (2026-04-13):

Research Inventy: International Journal of Engineering And Science Vol.14, Issue 5 (May 2024), PP 57-68
Issn (e): 2278-4721, Issn (p):2319-6483, www.researchinventy.com

# Carbon Capture and Storage using DAC Technology

## 1Vaibhav Kashid, 2Bhoomy Lingras, 3

## Shreyash Desai, 4Archit Kulkarni

1234Students, Department of Electronics & Telecommunication, KIT’s College of Engineering, Maharashtra, India
Corresponding Author: Prof. Atul R. Nigavekar

Abstract: Direct Air Capture (DAC) technology has attracted a lot of interest as a possible way to remove carbon dioxide (CO2) directly from the atmosphere, thereby reducing the effects of climate change. This in depth study offers a thorough analysis of DAC technology, emphasizing its underlying ideas, most current developments, difficulties, and incorporation with carbon capture and storage (CCS) plans. In the context of global climate mitigation efforts, this study tries to clarify the current state of distributed agriculture (DAC), as well as its viability, limitations, and future possibilities, through a thorough analysis of scientific literature, technical advancements, and real-world applications.
Keywords: Solenoid valves, Signal Conditioning Unit, Arduino Mega, Sorbent Molecules, CO2 sensors ---------------------------------------------------------------------------------------------------------------------------------------
Date of Submission: 01-05-2024 | Date of acceptance: 10-05-2024
I. INTRODUCTION
The undeniable threat that climate change poses to our planet is principally caused by the atmospheric build-up of greenhouse gases, most notably carbon dioxide (CO2). These gases trap heat, raising global temperatures, upsetting weather patterns, and having an adverse effect on the environment and society. In addition to lowering greenhouse gas emissions, we also need to look at ways to remove the CO2 that is already in the atmosphere. Here, Direct Air Capture (DAC) shows itself to be a technologically promising approach. DAC technologies are designed to take CO2 out of the air directly. While carbon capture and storage (CCS) systems concentrate on emissions from certain sources, such as power plants, distributed carbon dioxide (DAC) can target CO2 that is diffused throughout the atmosphere. There is potential for using the CO2 gathered in a number of different industrial areas. DAC facilities now function as experimental projects with constrained capture capacities.
There will need to be a great deal of research and development done if these technologies are to be scaled up to have a meaningful impact on atmospheric CO2 levels. Even if DAC is now quite expensive, economies of scale and technological developments are essential to improving accessibility. Not withstanding these obstacles, research on DAC is moving forward quickly.
The on going development of materials, capture techniques, and integration with renewable energy sources underscore the promise of DAC as an effective weapon in the fight against climate change. In this study, a conceptual design of a DAC system using an Arduino Mega microcontroller is explored. We will examine its elements, features, and possible advantages while recognizing its current drawbacks and places in need of more study.

II. LITERATURE SURVEY
1. Research Theories

The literature study offers a thorough summary of pertinent studies and research on the current theories and procedures used in CCS DAC technology. The main conclusions and insights from a variety of sources are highlighted in this overview of the literature, highlighting the importance and potential influence of the aforementioned technologies in resolving the issues that current practitioners confront.

Source 1: Intergovernmental Panel on Climate Change (IPCC) of the World Meteorological Organization (WMO) "CARBON DIOXIDE CAPTURE AND STORAGE (2005)"
Results: Special Report outlining the origins, sequestration, transportation, and storage of CO2. It also covers the technology's expenses, economic prospects, and societal concerns, such as regulatory and public perception.

Source 2: "A Knowledge Mapping-Based Study on the Development of Carbon Capture and Storage Technology," by Authors Hong-Hua Qiu and Lu-Ge Liu, Article MDPI, published in May 2018.

Carbon Capture and Storage using DAC Technology

Results: Carbon emissions and environmental protection, research and development activities, and socially relevant issues are among the topics covered in detail. In the meantime, the main emerging trends in the field of CCS technology research are emerging materials, emerging techniques and processes, evaluation of technological performance, and socioeconomic analysis.

Source 3: Natalia Kulichenko and Eleanor Ereira's "Carbon Capture and Storage in Developing Countries: A Perspective on Barriers to Deployment", a study conducted by the World Bank.
Results: Project Financing for Carbon Capture and Storage Power Plants in Developing Nations (Ch-6, pp. 80– 106)

Source 4: "Direct Capture of CO2 from Ambient Air" Eloy S. Sanz-Perez, Christopher R. Murdock, Stephanie
A. Didas, and Christopher W. Jones from the Department of Chemical and Environmental Technology, ESCET, Rey Juan Carlos University, C/Tulipan s/n, 28933 Mo Ástoles, Madrid, Spain, and the School of Chemical & Biomolecular Engineering, Georgia Institute of Technology, 311 Ferst Drive, Atlanta, Georgia 30332-0100, United States, contributed to this work.
Results: A thorough explanation of the chemical sorbents used in this application, including solvents and solid sorbents that interact strongly with CO2, is provided, with the main chemical sorbent classes being metal-organic frameworks (MOFs), supported amine and ammonium materials, and basic solvents. The field of DAC has a lengthy history.

The literature study concludes by highlighting the significance of pertinent studies and research on the current theory and procedures used in CCS DAC technology. It demonstrates how CCS DAC technology may significantly improve the environment and support sustainability objectives. These results provide a solid basis for the advancement and room-scale application of CCS DAC technology.

2. Provide feedback and practice

One of the main environmental issues and the cause of global climate change is carbon dioxide (CO2). This overview covers numerous organizations, tactics, and policy bodies while examining current doctrine and practice on the avoidance and reduction of greenhouse gas emissions through September 2021. i.e., CCS, or carbon capture and storage: The idea is to store CO2 emissions underground after they are captured at the source.
Use:
i. To keep CO2 out of the atmosphere, CCS technology is applied in electrical and industrial facilities.
ii. Strategies for cutting greenhouse gas emissions: Every year, tens of billions of tons of greenhouse gas emissions are discharged into the atmosphere, despite all of the efforts made to cut them. Consequently, the IPCC suggested that, in order to stop the increase of CO2 in the atmosphere, CO2 capture technology is essential. The conventional focus of CO2 collection has been on emissions from big stationary sources, like steel and metal industries, cement facilities, oil refineries, and fossil power plants.
These technologies are typically used in the production of synthesis gas (H2) and natural gas (CO). Feedstocks appropriate for energy generation and CO2 capture can be produced by a number of methods, such as gasification of coal (IGCC), coke, or oil wastes (reaction 2), or reforming oil (reaction 1). Reaction 3: A gas primarily consisting of CO2 and hydrogen is produced when CO and water react, also known as the water gas reaction. Pure H2 can be used to generate electricity by eliminating CO2. Under these conditions, CO2 concentrations range from 15 to 60%, making it easy to capture. However, the initial stage of fuel preparation for oil reforming and coal mining is costly and challenging.
CxHy + xH2O → xCO + (x + y/2)H2 | ...(1)
CxHy + x/2 O2 → x CO + y/2 H2 | ...(2)
CO + H2O → CO2 + H2 | ...(3)
3. Received during combustion
CO2 can also be retained in the flue gas released after combustion. A number of technologies can be used in this way, as there is no need to replace existing combustion equipment. Flue gas must normally be removed first, as required by law in most countries. The main effect of this approach is to reduce CO2 emissions from 4% by volume for combined natural gas power plants to 13-15% for coal fired power plants. Average global temperature changes from 2006 to 2100 were determined by multimodal simulations. All changes relate to the period 1986-2005. This review describes advances in the direct removal of CO2 from ambient air using adsorbents or direct air capture (DAC), one of several potential “carbon technologies.” The history of the DAC begins with the initial presentation of the atmosphere, followed by the assessed activities important for identifying the number of organisms and removing CO2 from the atmosphere. A brief discussion of informal methods based on DAC is also included. Finally, an overview of the feasibility and cost performance of DAC is presented.
4. Send fire
The flue gas that is emitted after burning contains the ability to hold CO2. This allows for the application of many different technologies without requiring the replacement of current combustion equipment. In most countries, it is legally required to remove flue gas first. This strategy's primary result is a decrease in CO2 emissions, which go from 4% of total emissions from combined natural gas power plants to 13-15% from coal-fired power plants. Using multi-model simulations, the average global temperature increases from 2006 to 2100 were calculated. Every modification relates to the years 1986–2005. This article details developments in direct air capture (DAC), one of several possible "carbon technologies" or the removal of CO2 directly from ambient air using adsorbents. The first presentation of the atmosphere in the history of the DAC is followed by an assessment of the activities crucial to determining the quantity of organisms and extracting CO2 from the atmosphere. Included is a brief explanation of unofficial techniques based on DAC. Lastly, a summary of DAC’s cost effectiveness and viability is given.

III. COMPONENTS SELECTION

1. Microcontroller Board: -

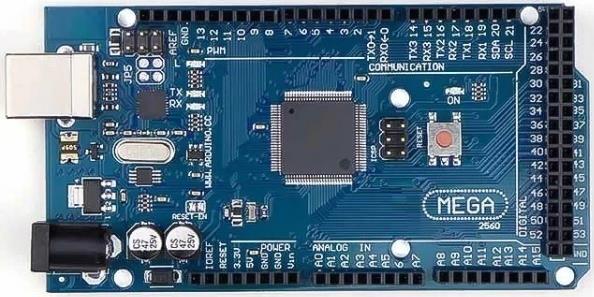
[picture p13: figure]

The following summarizes the main considerations that led us to choose the Arduino Mega 2560 for this project: There are a few main reasons why the Arduino Mega microcontroller board was selected.

- Wide Range of I/O Capabilities: With so many digital and analog input/output ports available, the Arduino Mega is a great choice for attaching and managing numerous sensors, actuators, and peripherals at once. This is important for a project like DAC technology, where a large number of sensors may be used for data collection, control, and environmental monitoring.
- Processing Capacity: The Arduino Mega has enough processing power and storage to manage intricate algorithms, data processing jobs, and control logic needed in DAC systems thanks to its ATmega2560 processor, which runs at 16 MHz, and large flash memory (256 KB). This is crucial for the system's decision-making, control, and real-time monitoring procedures.
- Community Support and Compatibility: A large developer, maker, and enthusiast community supports Arduino boards, including the Mega. This guarantees a large selection of suitable libraries, sample programs, tutorials, and community forums where you can ask questions, exchange ideas, and work through problems that arise while working on the project. This network of help can greatly accelerate development and lessen implementation difficulties.
- Expandability and Modularity: The Arduino Mega modular design facilitates effortless expansion via shields and modules, offering the opportunity to incorporate supplementary features or interact with external devices as required for your DAC technology endeavor. It is advantageous that the system can be scaled up or down in the future.
- Cost Effectiveness: The Arduino Mega offers a balance of functionality, performance, and price when compared to some other microcontroller boards with comparable capabilities. Because of this, it is an affordable option for projects like the development of Direct Air Capture technology that have rigorous I/O needs and processing duties.

In general, the Arduino Mega is a good and useful option for implementing the control and monitoring components of your DAC system because of its wide range of I/O capabilities, processing power, interoperability, community support, expandability, and affordability.

Specifications:

- Microcontroller: ATmega2560
- Operating Voltage: 5V
- Input Voltage (recommended): 7-12V
- Input Voltage (limits): 6-20V
- Digital I/O Pins: 54 (of which 15 provide PWM output)
- Analog Input Pins: 16
- DC Current per I/O Pin: 20 mA
- DC Current for 3.3V Pin: 50 mA
- Flash Memory: 256 KB (8 KB used by bootloader)
- SRAM: 8 KB
- EEPROM: 4 KB
- Clock Speed: 16 MHz
2. Pressure Sensor: -

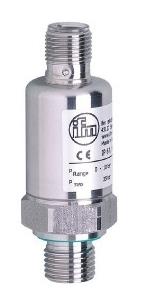
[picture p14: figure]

Because the PT9544 pressure sensor is appropriate for measuring pressure in the setting of vacuum systems and atmospheric circumstances, it is utilized.

- Pressure Range: Typically, the PT9544 sensor can measure a wide range of pressures, from ambient pressure to vacuum levels. This range is crucial to DAC technology, as measurements of pressure might range from lower pressures in the capture and storage systems to ambient air pressure.
- Accuracy and Precision: The PT9544 sensor provides accurate and precise pressure measurements, which is necessary for DAC operations to record accurate data. Precise pressure measurements are essential for overseeing and managing the functioning of air collection systems, guaranteeing maximum effectiveness and productivity.
- Small and Adaptable: The PT9544 sensor's small size makes it simple to incorporate into your DAC system without taking up a lot of room. Because of its adaptability, installation options are diverse and precise pressure measurements may be made at strategic spots in the collection and storage infrastructure.
- Durability and Reliability: Equipped with characteristics that improve durability in a range of environmental situations, the PT9544 sensor is built for dependable long-term performance. This dependability adds to the overall efficacy and stability of the technology by enabling continuous and precise pressure monitoring in DAC systems.

Specifications:

- Pressure Range: Typically, 0 to 10 bar (other pressure ranges may be available)
- Output Signal: Analog (0-10V or 4-20 mA)
- Supply Voltage: 10-30 VDC
- Accuracy: ±0.5% of Full Scale (FS)
- Operating Temperature: -25°C to 85°C
- Process Connection: G1/4" male thread
- Electrical Connection: M12 connector or cable
- Material: Stainless steel (housing)
- Protection Rating: IP65/IP67 (depending on the variant)
3. CO2 Sensor:-

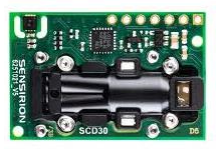
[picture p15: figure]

There are a number of strong reasons why the Sensirion Non-Dispersive Infrared (NDIR) CO2 sensor was chosen.

- Precise CO2 Measurement: NDIR sensors are renowned for their exceptional precision in determining CO2 levels. This is crucial for Direct Air Capture (DAC) systems, as accurate air level monitoring is necessary for efficient CO2 capture and storage. The Sensirion NDIR CO2 sensor is known for its broad measurement range, which enables it to precisely monitor CO2 concentrations ranging from ambient levels to higher amounts encountered in DAC operations.
- Stability and Long-Term Performance: NDIR technology is appropriate for continuous monitoring and control applications in DAC systems because it offers steady and trustworthy CO2 measurements over long periods of time. Maintaining the efficacy and efficiency of CO2 capture and storage operations requires consistent performance.
- little Power Consumption: Sensirion's CO2 sensors, among others, are made to function with little power consumption. This is helpful for energy efficient operation, particularly in off grid or remote distributed air conditioner installations where power conservation is a top concern.

Specifications:

- Measurement Principle: Non-Dispersive Infrared (NDIR)
- Carbon Dioxide (CO2) Measurement Range: 0-40,000 parts per million (ppm)
- Accuracy: ± (30 ppm + 3% of measured value) within 400-10,000 ppm
- Response Time: <2 minutes (for 63% step change)
- Temperature Range (Operating): 0°C to 50°C
- Humidity Range (Operating): 0% to 100% RH (non-condensing)
- Supply Voltage: 3.3 V to 5.5 V
- Communication Interface: I2C (up to 400 kHz) and UART (up to 115200 bps)
- Dimensions: 35.6 mm x 23.3 mm x 3 mm (L x W x H)
- Digital Output Resolution: 16-bit
- Power Consumption (Average): 19 mA @ 3.3 V (continuous operation)
- Warm-up Time: <30 seconds

4. Molecular Sieves:-

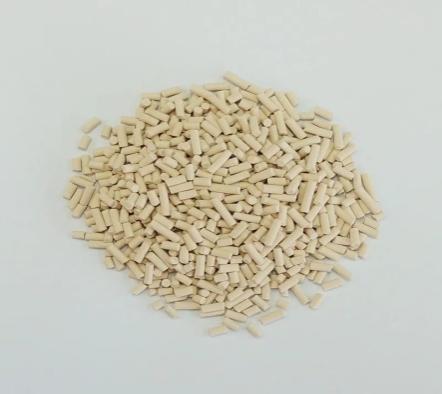
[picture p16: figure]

Because of its numerous uses, 13x molecular sieves were specifically taken into consideration.

- Selective Adsorption: Molecular sieves are engineered to adsorb molecules of particular sizes in a selective manner. The capacity of 13x sieves to specifically adsorb CO2 from air while permitting other gases, such as oxygen and nitrogen, to flow through, is well recognized.
- High Capacity: 13x molecular sieves can absorb a large amount of CO2 per unit weight or volume of the sieves thanks to their high CO2 adsorption capacity. This large capacity is essential for effective digital audio converters.
- Regenerability: Molecular sieves can be utilized again and again by desorbing the CO2 that has been absorbed. As a result, they are more economical and eco-friendly than one-time use adsorbents.
- Stability: 13x molecular sieves remain stable in a variety of working environments, such as those with fluctuating pressures and temperatures that are typical of DAC systems.
- Commercial Availability: Due to their vast commercial availability, these sieves are easily accessible for large-scale DAC projects. Details: Molecular sieves of type 13x (Type x) with a pellet diameter of
1.6 mm (other diameters may also be offered)

Specificaions:

- Adsorbate: primarily used for CO2 adsorption from air;
- Pore Size: approximately 10 angstroms (1 nanometer), suitable for capturing CO2 molecules while allowing smaller molecules like nitrogen and oxygen to pass through;
- Surface Area: typically ranges from 600 to 800 square meters per gram (m2/g), providing a large surface area for CO2 adsorption;
- Adsorption Capacity: can adsorb a significant amount of CO2 per unit weight of molecular sieves, depending on the particular conditions and activation level;
- Regenerability: molecular sieves are regenerable by desorbing the captured CO2, making them economical and environmentally friendly;
- Material: typically composed of zeolite materials such as sodium aluminosilicate

5. Temperature sensor:-


For several reasons, Direct Air Capture (DAC) projects frequently use PT100 sensors, usually referred to as platinum resistance temperature detectors (RTDs).

- Accuracy: Temperature-sensitive operations in DAC systems require constant monitoring and control, and PT100 sensors provide this critical accuracy. Accurate temperature regulation is frequently required for maximum effectiveness and performance.
- Stability: The stability and little drift over time of PT100 sensors are well-known. This guarantees that temperature readings stay accurate and consistent for the duration of the DAC system's operation, which results in consistent process performance.
- Linear reaction: The PT100 sensors provide a linear reaction to temperature variations, which facilitates precise calibration and interpretation of temperature measurements. In DAC processes, this linear response helps to preserve particular temperature setpoints.
- Broad Temperature Range: PT100 sensors are capable of functioning in a broad temperature range, which encompasses the high temperatures that might be encountered in DAC systems during specific procedures like as CO2 desorption or adsorbent renewal.
- Compatibility: The PT100 sensors may be easily integrated into DAC technology projects since they are compatible with conventional measurement and control systems that are frequently used in industrial settings.
- Industry Standard: Because of their accuracy, stability, and dependability, PT100 sensors are widely utilized and well established in a variety of sectors for temperature sensing applications. For many DAC technology projects where accurate temperature control and monitoring are crucial, this makes them the preferable option.

Specifications:

An example of a platinum resistance temperature detector (RTD) is the PT100 temperature sensor, which comes with the following specifications:

Type: PT100 (Platinum RTD)

- Temperature Range: -200°C to 850°C (-328°F to 1562°F) is the temperature range that standard PT100 sensors can measure. It's possible that PT100 sensors with extended range can measure temperatures more broadly.
- Precision: PT100 sensors have a high degree of precision; depending on the grade and calibration, they can often measure within ±0.1°C to ±1°C.
- Resistance at 0°C: A PT100 sensor's resistance, which increases linearly with temperature changes, is 100 ohms at 0°C, hence the designation PT100.
- Temperature Coefficient: PT100 sensors temperature coefficient of resistance, which is utilized in computations to translate resistance variations into temperature readings, is roughly 0.00385 ohms/ohm/°C.
- Construction: To create a resistance element, platinum wire is usually coiled around a ceramic or glass core in PT100 sensors. 14

- Response Time: For the majority of applications, PT100 sensors respond rather quickly within a few seconds, on average. Depending on the PT100 sensors manufacturer, model, and grade, these specs may change slightly. It's crucial to consult the datasheet supplied by the sensor manufacturer to find the details pertaining to a particular PT100 sensor model
6. Solenoid Valve:-

24 volt DC solenoid valves:

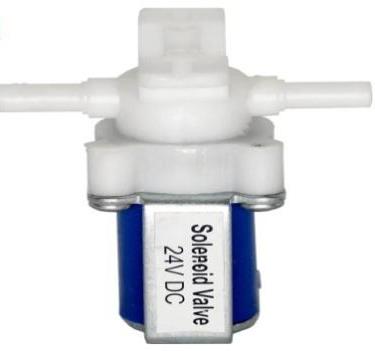
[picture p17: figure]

- Controlled Gas Flow: In DAC systems, solenoid valves regulate the flow of gases like air and CO2. Their ability to precisely regulate gas flow rates is essential for preserving ideal process conditions throughout the CO2 capture, release, and storage stages.
- Automation: Gas flow regulation can be automated with solenoid valves, eliminating the need for human modifications. Because this automation can be linked into control systems and designed to work according to preset parameters, it enhances system efficiency, consistency, and reliability.
- Response Time: The quick response times of solenoid valves allow for quick opening and closing of the valve. This fast reaction is useful for making quick changes to gas flow rates, particularly when there are dynamic process circumstances or when the system calls for it.
- Compatibility: 24V DC solenoid valves are easily integrated into DAC technology projects since they work with standard power sources and industrial control systems.

Specifications:

- Voltage: Direct Current, 24 V DC
- Type of Valve: Normally Closed (NC), which means that when the solenoid coil is not receiving any power, the valve is closed and opens when it is.
- Operating Pressure Range: Depending on the particular model and application requirements, solenoid valves for industrial usage may often withstand pressures ranging from 0 to several hundred pounds per square inch (psi).
- Flow Rate: Depending on the size and design of the valve, the solenoid valves flow rate is expressed in liters per minute (LPM) or gallons per minute (GPM). A few GPM to several tens of GPM are typical flow rates.
- Valve Size: Solenoid valves are available in a range of sizes, including 1/4-inch, 1/2-inch, 3/4-inch, and 1 inch

IV. BLOCK DIAGRAM

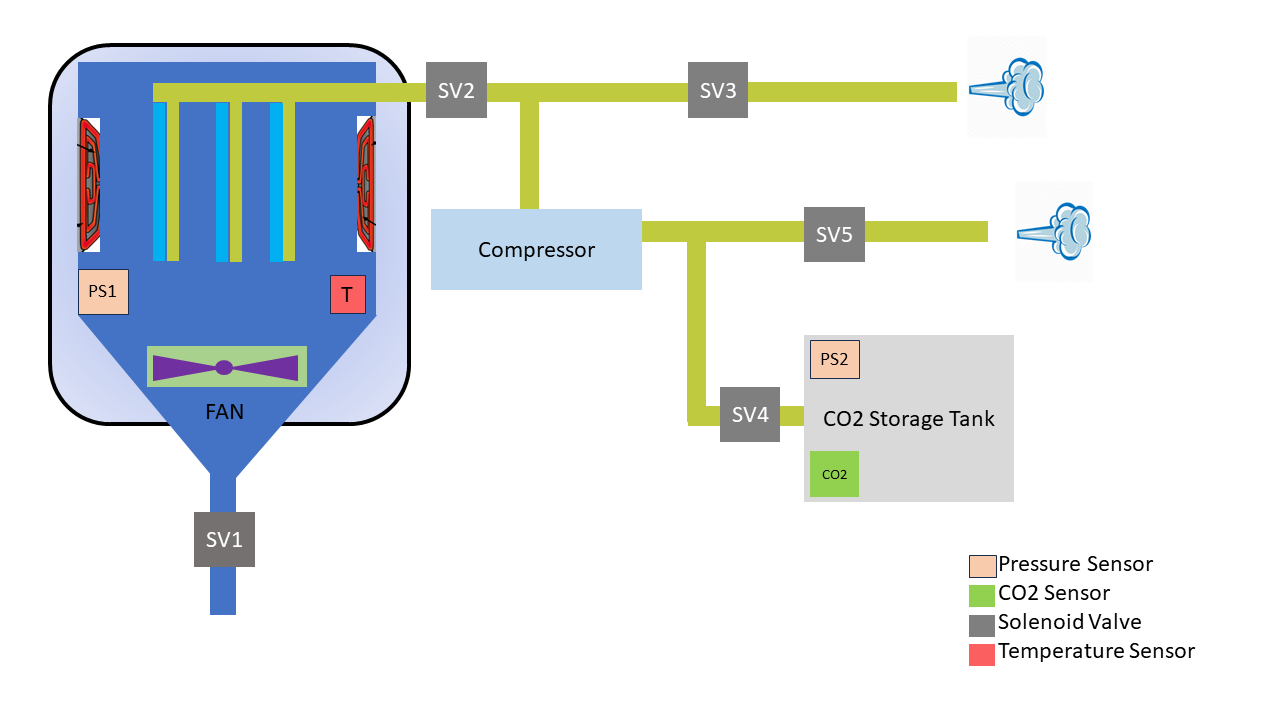
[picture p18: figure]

Fig. Carbon Capture and Storage using DAC Technology

The system's needed flow capacity is taken into consideration while choosing the valve size. Block Schematic The functional architecture of our DAC Technology is shown in the block diagram above.
1. Solenoid Valves
Valves with solenoids A solenoid valve is a crucial component of Direct Air Capture (DAC) technology, performing functions like controlling gas flow, purging and ventilating, regulating pressure, ensuring safety shutdown, and automating processes. Think about things like valve type, material compatibility, pressure and temperature ratings, and electrical compatibility with your control system when choosing a solenoid valve. 16
2. Nichrome Wire
Nichrome Wire Because of its high electrical resistance, nichrome wire is used in DAC systems to provide controlled and consistent heating, which is necessary for thermal operations. It is perfect for heating elements in our project, helping to ensure effective carbon capture operations. Its temperature stability, corrosion resistance, and compatibility with electrical systems, including microcontrollers like the Arduino Mega, further contribute to its advantages.
3. Fan
A fan Fans are necessary for ventilation, pressure management, temperature regulation, air circulation, and cooling electronic components. Efficient CO2 capture and processing while preserving system reliability and performance can be achieved by selecting a fan that meets your control system's requirements for size, power consumption, noise level, airflow capacity, and compatibility.
4. CO2 sensor
A CO2 detector When it comes to tracking and detecting carbon dioxide (CO2) concentrations, the CO2 sensor is essential. The sensor gives accurate control and optimization of DAC processes by providing real-time data on CO2 levels. This information is essential for guaranteeing proper CO2 collecting, storage, and processing, which enhances the DAC system overall efficacy and environmental impact.
5. Pressure Sensor
Sensor of Pressure The system pressure levels are measured and observed using the PT9544 pressure sensor. In order to maintain proper pressures for gas flow, regulate pressure changes throughout processes, and improve overall system performance and efficiency, this sensor is essential to guaranteeing ideal operating conditions.
6. 16x2 LCD Display
16X2 LCD Display Real time data, system status, and operational parameters can all be shown using an LCD display as a user interface. It gives temperature, pressure, and CO2 levels a visual representation.

7. Temperature Sensor

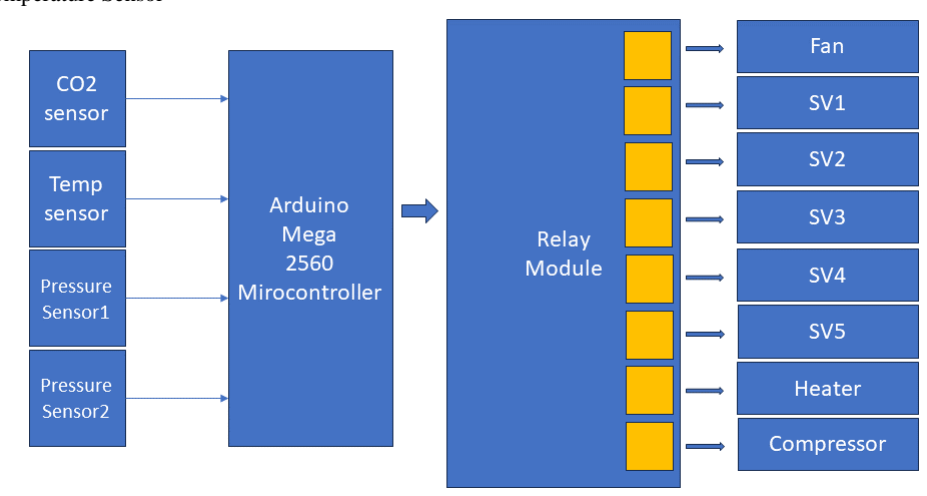
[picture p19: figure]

Thermostat For precise temperature monitoring and control during the CO2 collecting and storage procedures, PT100 sensors are necessary. By keeping temperatures within the necessary range, enabling automated control, facilitating data analysis, and promoting adsorbent material regeneration cycles, they ensure optimal operation, safety, and process efficiency. PT100 sensors are vital instruments for optimizing the efficiency of DAC systems in the fight against climate change since they interface with control systems in a fluid manner.

V. CIRCUIT DIAGRAM

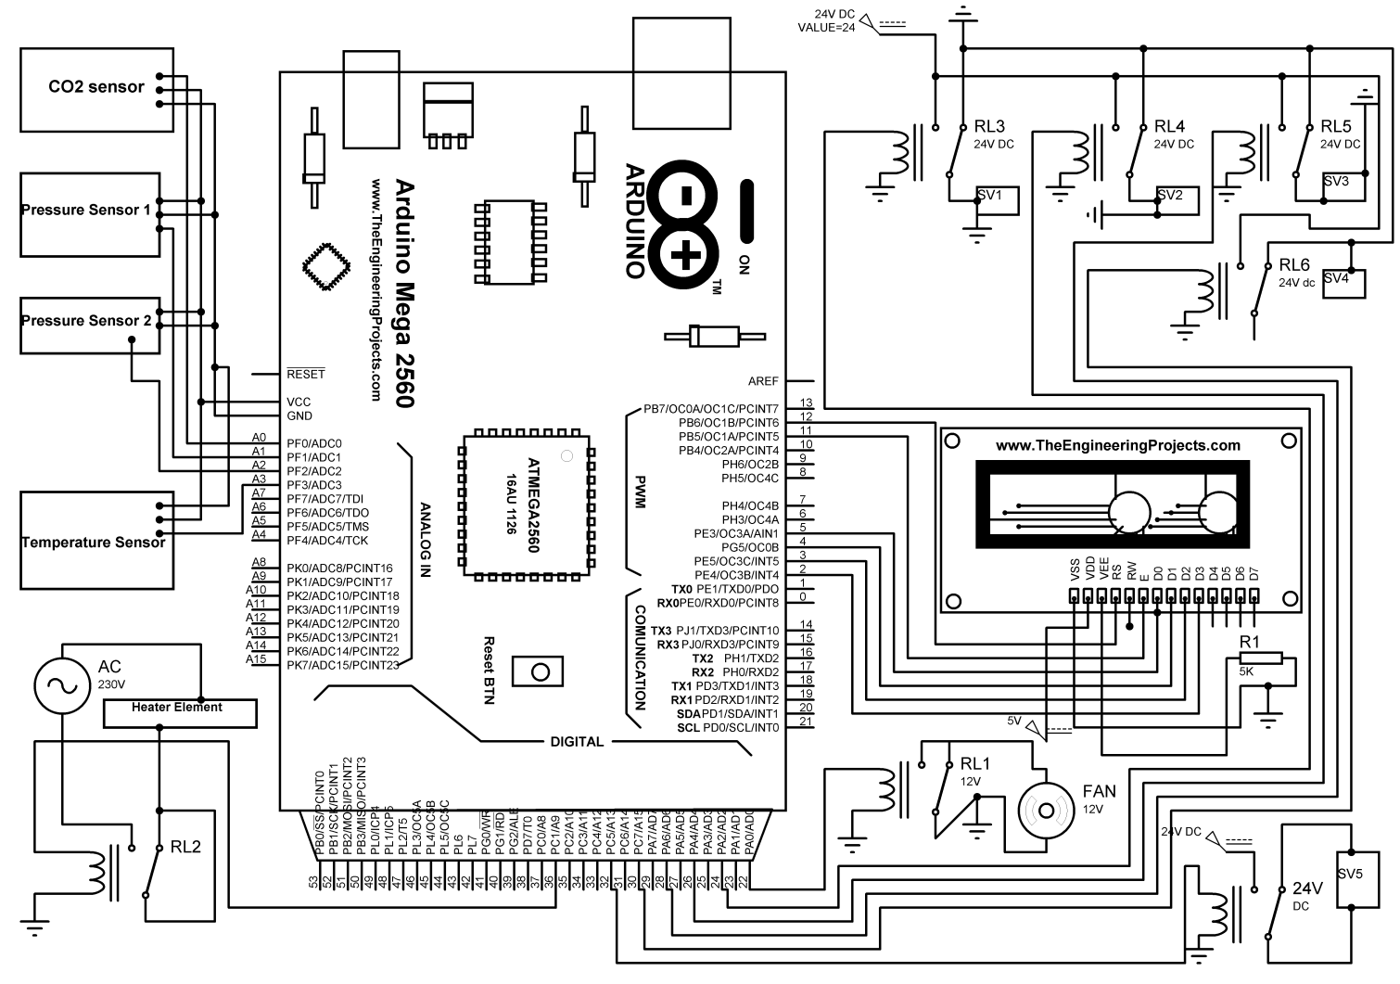
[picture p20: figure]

VI. EXPERIMENTAL PROCEDURE

1. Inserting Molecules in Chamber
Placing Molecules into the Chamber. There are three distinct sorbent panels that make up the chamber. Each had the ability to store 500 grams of 13x molecular sieves.
2. Air Flow
Movement of Air Activate the compressor and fan. Solenoid valves 1,2 and 3 should be opened, while solenoid valves 4 and 5 should be closed. As a result, air will be able to flow between the molecules.
3. Creating vacuum in chamber
Producing a vacuum inside the container Now shut off solenoid valve 1 and the fan. Sorbent molecules will absorb CO2 from the air at room temperature, and any leftover airborne particles will be drawn up by a compressor and expelled through Solenoid Valve 2 and 5. This procedure will continue until the vacuum pressure reaches a predetermined limit. The PT9544 pressure sensor measures this pressure. The compressor will then cause solenoid valves 2 and 5 to shut off.
4. Giving heat to the Molecular Sieves
Increasing the Molecular Sieves temperature Right now With the use of a heating element made of nichrome wire, warm the molecules to a steady temperature of 75o

± 4oC. Here, the microcontroller is configured to function as a thermostat. If the temperature rises over 75o
, it will cut off the supply to the Nichrome Wire. If the temperature falls below 75 o
, it will turn on the supply. For thirty minutes, this process will continue
5. Storing CO2 in Tank and displaying its Concentration
Holding CO2 and showing its concentration in a tank To store the released CO2 from molecules in the tank, open Solenoid Valve 2 and 4 and turn on the compressor. The compressor and solenoid valves 2 and 4 will turn off when the designated level is reached. The CO2 concentration in parts per million will then be shown on a 16x2 LCD screen.

VII. FUTURE SCOPE

When considering the potential applications of direct air capture (DAC) technology for carbon capture and storage (CCS), a number of fascinating research and development opportunities arise that have the potential to completely transform how we tackle climate change.

1. Enhanced Carbon Capture Efficiency: By investigating new materials, cutting edge sorbents, and creative capture strategies, future research may concentrate on improving the effectiveness of DAC systems. DAC technology can be rendered more economical and expandable by increasing the rate of CO2 removal and decreasing energy usage through the optimization of the capture process.
2. Carbon Negative Solutions: Building on the success of the DAC, further research may focus on creating carbon negative solutions that eliminate carbon emissions now in place in addition to removing CO2 from the environment. This could entail using natural processes like increased weathering to trap carbon in soils or minerals, or it could entail combining DAC with bioenergy with carbon capture and storage (BECCS).
3. Hybrid Approaches: There is a great deal of potential for synergistic effects when hybrid approaches, like point source capture from industrial sites or power plants, combine DAC with other carbon capture technologies. To construct integrated carbon capture and storage (CCS) systems that maximize carbon removal capacities while minimizing costs and environmental concerns, research might investigate the integration of DAC with currently in place infrastructure.
4. Carbon Utilization and the Circular Economy: In addition to storage, further study may concentrate on using collected carbon as a useful resource in the creation of sustainable materials, chemicals, and fuels. By adopting the circular economy's tenets, DAC technology can help build closed loop systems that recycle and reuse CO2, lessening dependency on finite resources and lessening environmental effects.
5. Community Engagement and Social Acceptance: Given the significance of including stakeholders, community involvement and social acceptance in the implementation of DAC technology might be given priority in future studies. Researchers can make sure that DAC initiatives are carried out in a way that benefits all stakeholders and advances sustainable development by encouraging communication, establishing trust, and addressing concerns about environmental justice and equity.
6. International Collaboration and Knowledge Sharing: To advance DAC technology and hasten its global application, international collaboration is crucial. Future studies should concentrate on developing international collaborations, exchanging best practices, and promoting the flow of knowledge in order to get over financial, legal, and technical obstacles and encourage the broad use of DAC as a vital weapon in the battle against climate change. All things considered, research on direct air capture technology for carbon capture and storage has a bright future full of potential for creativity, teamwork, and good deeds.

Researchers can fully realize the potential of DAC as a game changing tool in our joint efforts to create a future that is more robust and sustainable by embracing these new lines of inquiry.

VIII. CONCLUSION
The potential of Direct Air Capture (DAC) in conjunction with Carbon Capture and Storage (CCS) to reduce CO2 emissions is highlighted in the conclusion. It highlights the technical features of DAC, such as 13x molecular sieves, sophisticated materials, and energy efficient operations, as well as its scalability and efficiency. In order to advance research, cut costs, and implement CCS DAC solutions globally and contribute to a sustainable, carbon-neutral future, collaboration is essential

ACKNOWLEDGEMENT
We want to sincerely thank everyone who helped us finish this research work on the subject of "Carbon Capture & Storage using Direct Air Capture Technology". We also appreciate Prof. A. R. Nigavekar and Dr. Y.
M. Patil, Sir, who are faculty members of KIT's College of Engineering, for their support and for providing us with the tools we needed to complete this review.

REFERENCES
[1]. J. Godin, W. Liu, S. Ren, C.C. Xu Advances in recovery and utilization of carbon dioxide: A brief review J. Environ. Chem. Eng., 9
(4) (2021), Article 105644
[2]. A.D. Kamkeng, M. Wang, J. Hu, W. Du, F. Qian Transformation technologies for CO2 utilization: Current status, challenges and future prospects
[3]. C.F. Heuberger, I. Staffell, N. Shah, N.M. Dowell Quantifying the value of CCS for the future electricity system Energy Environ. Sci., 9 (8) (2016), pp. 2497-2510
[4]. X. Xiao, J. Gu, W. Liang, Q. Yu, M. Tang Application of carbon dioxide capture, storage and utilization technology Guangzhou. Chem. Ind., 50 (03) (2022), pp. 26-29
[5]. | A Systematic Review of Carbon Capture, Utilization and Storage: Status, Progress and Challenges
[6]. | pubmed.ncbi.nlm.nih.gov/37269511

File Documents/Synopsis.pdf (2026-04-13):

CO2

# Decomposer

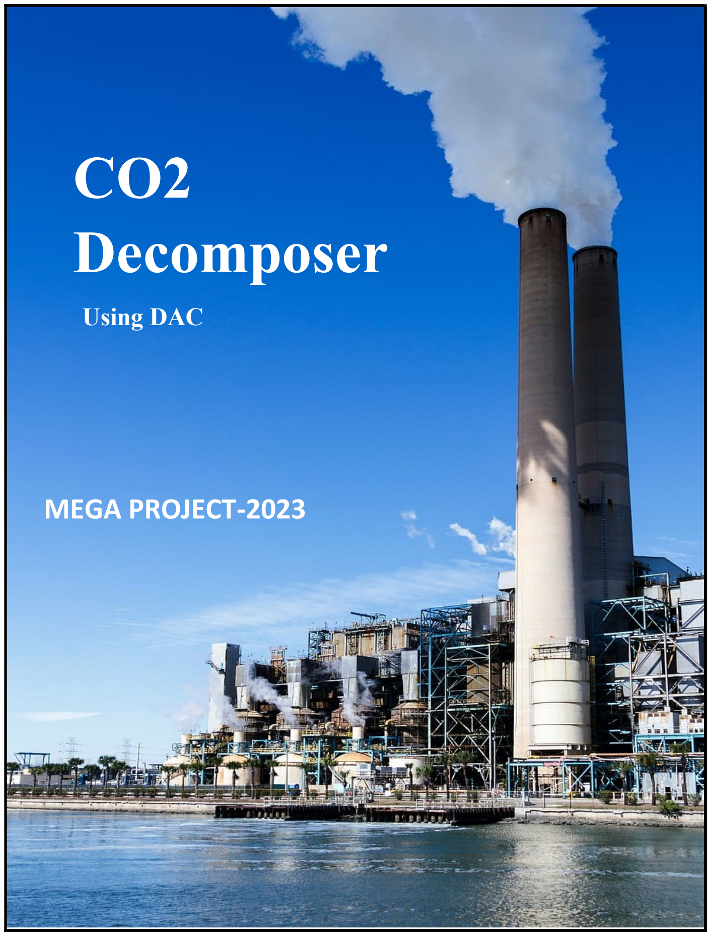
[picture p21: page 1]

0

# MEGA PROJECT-2023

## Using DAC

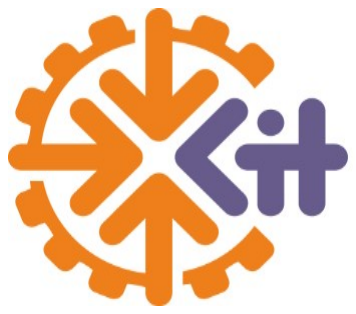
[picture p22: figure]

1

## Direct Air Capture and Storage Technology

A Synopsis on

Submitted by

## ARCHIT RAGHAVENDRA KULKARNI: 2122010119 VAIBHAV RAMESH KASHID: 2021000347 BHOOMY DURGESH LINGRAS: 2021000722 SHREYAS AMRUT DESAI: 2021000732

In partial fulfilment for the award of the degree of

### Electronics and Telecommunication

Under the guidance of

### Prof. Atul Nigvekar

THE FACULTY OF MEGA PROJECT

## Department of Electronics and Telecommunication Engineering

KIT’s College of engineering, Kolhapur 2023-24

2

# INDEX

CHAPTER NO. | TITLE | Page No.
1 | PROBLEM STATEMENT | 4
2 | RELEVANCE | 5
3 | LITERATURE SURVEY | 7
4 | PRESENT THEORIES AND PRACTICES | 10
5 | OBJECTIVES AND SCOPE OF PROJECT | 12
6 | RESEARCH METHODOLOGY | 15
7 | PROJECT REQUIREMENTS | 17
8 | REFERENCES | 19

## Problem Statement

The rising levels of atmospheric carbon dioxide (
global climate stability. Current efforts to reduce
industrial processes and transportation are insufficient to meet targets. Currently, the Direct Air Capture (DAC) technology offers a promising solution but faces significant challenges in terms of cost
efficiency and scalability. The challenge is to optimize room technology via an open-source approach, iteratively improving DAC systems with crowd-sourced ideas and an open data set for experimentation.
are familiar with the potential
enhance carbon dioxide capture efficiency, prom
addressing climate change.

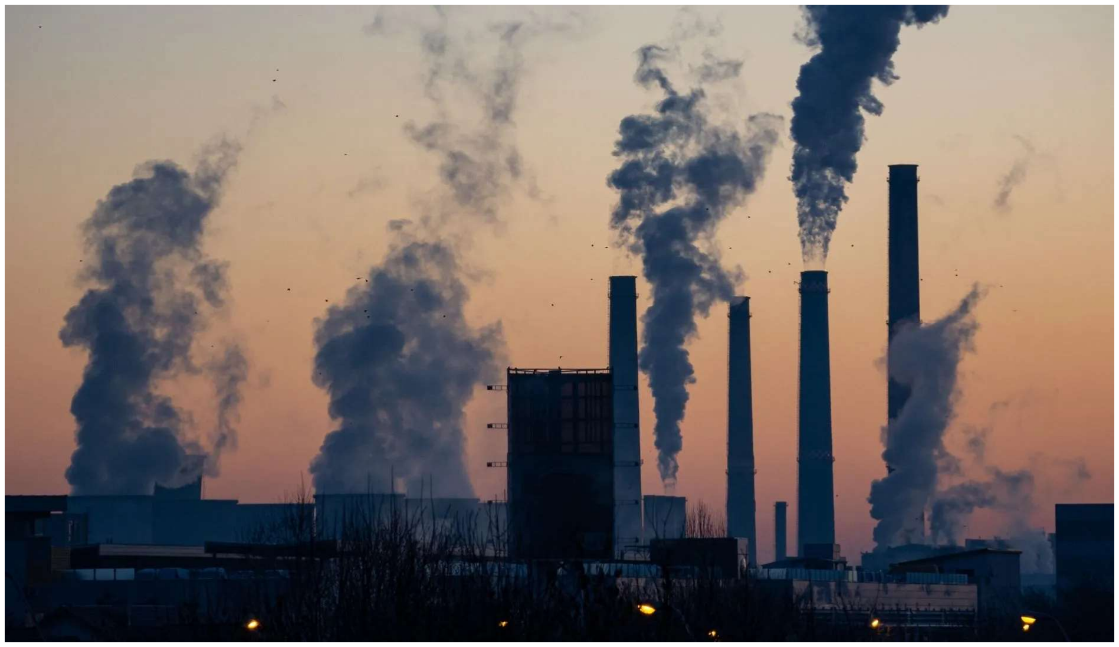
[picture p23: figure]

3

## Problem Statement

CO2) pose a critical threat to CO2 emissions from

Direct Air Capture (DAC) technology offers a promising -effectiveness, energy

source approach, iteratively improving DAC systems sourced ideas and an open data set for experimentation. consequences of CO2 therefore our oting sustainability and

emissions from
climate

-scale DAC

We all
goal is to

4

## Relevance

### What is DAC?

Direct Air Capture (DAC) is an advanced technology designed to remove CO2 directly from the Earth's atmosphere. It plays a crucial role in addressing climate change by actively reducing the concentration of CO2 (a major greenhouse gas responsible for global warming). DAC systems employ specialized chemical processes or absorbent materials to capture CO2 from the air. Once captured, the CO2 can be stored underground or utilized in various applications, such as in carbon-neutral fuels or carbon removal products. DAC offers a potential solution to combat climate change by helping to balance CO2 emissions and achieve net-zero or even negative emissions, thus contributing to a more sustainable and climate-resilient future.

The need of DAC.

The relevance of a project on DAC lies in its potential to address the urgent and escalating global climate crisis. With atmospheric CO2 levels reaching alarming concentrations, DAC offers a vital strategy to actively remove excess CO2 from the air, helping to mitigate climate change's adverse effects. DAC technology has the potential to complement traditional emissions reduction efforts and create a pathway towards achieving carbon neutrality. By developing cost-effective, energy-efficient, and scalable DAC solution, this project holds the promise of contributing significantly to global efforts to combat climate change and safeguard the future of our planet for generations to come.

5

## Literature Survey

The review of literature provides a comprehensive overview of relevant studies and research on the present theory and practices followed in DAC-CCS technology. This literature review highlights the key findings and insights from various sources, demonstrating the significance and potential impact of above mentioned technology in addressing the challenges faced by present practitioners.

Source 1: ” CARBON DIOXIDE CAPTURE AND STORAGE (2005)” * Intergovernmental Panel on Climate Change (IPCC) of WMO (World Meteorological Organization)*
Findings: Special Report which describes sources, capture, transport, and storage of CO2. It also discusses the costs, economic potential, and societal issues of the technology, including public perception and regulatory aspects.

Source 2: “A Study on the Evolution of Carbon Capture and Storage Technology Based on Knowledge Mapping” * Hong-Hua Qiu & Lu-Ge Liu writers, Article Published by MDPI (May2018)*
Findings: Detailed Information about the topics includes carbon emissions and environmental protection, research and development activities and social practical issues, meanwhile, the main emerging trends include emerging techniques and processes, emerging materials, evaluation of technological performance and socioeconomic analysis in the research area of CCS technology.

Source 3: “Carbon Capture and Storage in Developing Countries: A Perspective on Barriers to Deployment”* by Natalia Kulichenko & Eleanor Ereira A WORLD BANK STUDY*.
Findings: Project Finance for Power Plants with Carbon Capture and Storage in Developing Countries (Ch-6, pg 80-106)

6

Source 4: “Direct Capture of CO2 from Ambient Air” * By- Eloy S. Sanz-Perez, Christopher R. Murdock, Stephanie A. Didas and Christopher W. Jones* of School of Chemical & Biomolecular Engineering, Georgia Instute of Technology, 311 Ferst Drive, Atlanta, Georgia 30332-0100, United States and Department of Chemical and Environmental Technology, ESCET, Rey Juan Carlos University, C/Tulipan s/n, 28933 Mo ́stoles, ́Madrid, Spain*
Findings: A historical overview of the field of DAC and exhaustive description of the use of chemical sorbents targeted at this application, includes solvents and solid sorbents that interact strongly with CO2 are described, including basic solvents, supported amine and ammonium materials, and metal−organic frameworks (MOFs), as the primary classes of chemical sorbents.

Conclusion: The review of literature underscores the importance and relevant studies and research on the present theory and practices followed in DAC-CCS technology. It showcases how DAC-CCS technology can make a significant positive impact on the environment which contribute to sustainability goals. These findings serve as a strong foundation for the development and implementation of DAC-CCS technology at room scale

7

## Present Theories and Practices

Carbon dioxide (CO2) emissions are a major driver of global climate change and represent a pressing environmental challenge. This overview explores current theories and practices up to September 2021 concerning the prevention and reduction of CO2 emissions, encompassing various sectors, strategies, and policy frameworks.

### 1. Carbon Capture and Storage (CCS):

Theory: Involves capturing CO2 emissions at the source and storing them underground. Practice: Implementation of CCS technologies in power plants and industrial facilities to prevent CO2 from entering the atmosphere.

### 2. Processes for Reducing CO2 Emissions:

Despite all the efforts aimed at minimizing CO2 emissions, tens of billions of tons are still released every year. Thus, CO2 capture was proposed by the IPCC as a technology necessary to restrain the growth of the atmospheric CO2 concentration. Conventional CO2 capture has commonly addressed CO2 emissions from large stationary sources, such as fossil-fuelbased power stations, cement plants, oil refineries, and iron or steel industry installations, as examples. According to the different processes where carbon capture can be implemented, three main technologies are described.
2.1. Precombustion: These technologies are typically used when starting from natural gas or syngas (CO and H2). Several processes can be used to create suitable feeds for energy generation as well as CO2 separation, including steam reforming (reaction 1), as well as gasification of pulverized coal (IGCC), coke, or oil residues (reaction 2). The reaction between CO and water, the water gas shift reaction, yields a gas stream composed of primarily CO2 and hydrogen (reaction 3). The removal of CO2 yields a high-purity H2 stream available for electricity production. CO2 capture is relatively easy in these cases because its concentration ranges between 15 and 60%. On the other hand, the first steps of fuel preparation for coal gasification and steam reforming are challenging and expensive.

CxHy + xH2O → xCO + x +

H2 (1)

CxHy +

x
2

O2 → x CO +

y
2
H2 | (2)
CO + H2O → CO2 + H2 | (3)

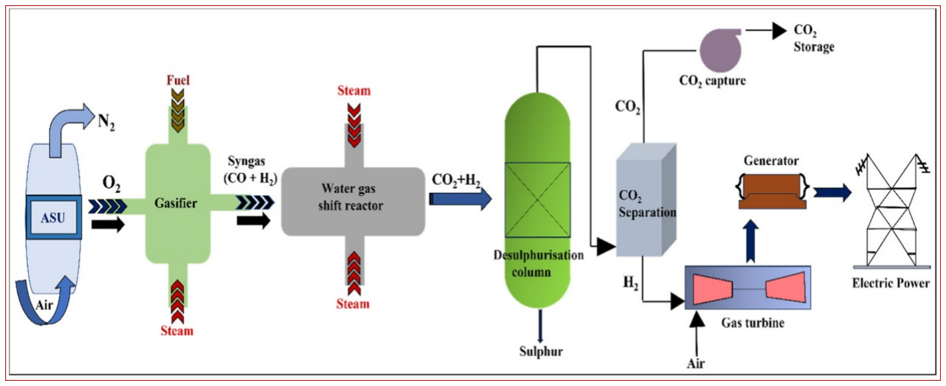
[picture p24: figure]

8

Fig. Depiction of pre-combustion CO2 capturing technique

### 2.2. Capture During Combustion: Two main technologies are used for capture during

combustion, oxy-fuel combustion and carbonation−calcinaon. Oxy-fuel processes carry out the combustion with pure oxygen instead of air. A part of the combustion gases is typically recirculated in such processes. The flue gas volume is considerably reduced by the use of oxygen instead of air, and the CO2 concentration is concomitantly increased (up to 90%). However, these technologies are not yet highly favored because of the high cost of the air separation needed to obtain pure oxygen.

### 2.3. Postcombustion: CO2 can also be captured from flue gas released after combustion. A

number of technologies can be used for this approach because existing combustion facilities do not need to be modified. Typically, the flue gas needs to be previously desulfurized to a great extent which is compulsory by law in most countries. The main disadvantage of this approach is the reduced CO2 concentration, which ranges from ∼4 vol % for a natural gas combined cycle processes to 13−15 vol % for a coal-fired combustion plant. Global average surface temperature change from 2006 to 2100 determined by multimodel simulations. All changes are relative to 1986−2005. Time series of projecons and a measure of uncertainty (shading) are shown for scenarios RCP2.6 (blue) and RCP8.5 (red). The mean and associated uncertainties averaged over 2081−2100 are given for all RCP scenarios as colored vercal bars at the right-hand side of each panel. The number of Coupled Model Intercomparison Project Phase 5 (CMiP5) models used to calculate the multimodel mean is indicated. Reprinted with permission from ref 5. Copyright 2014 IPCC.

9

Chemical Reviews Review DOI: 10.1021/acs.chemrev.6b00173 Chem. Rev. 2016, 116, 11840−11876 11841 such as SO2 and NOx are also a problem for many separation processes; for example, because of their reactivity toward amines, which are the compounds commonly used for postcombustion CO2 capture, amine-based separation processes require flue gas pretreatment to significantly reduce the concentrations of these strongly acidic gases. To date, large-scale postcombustion CO2 separation processes have been mainly based on liquid amine absorption techniques. Aqueous solutions of monoethanolamine (MEA), diethanolamine (DEA), and methyldiethanolamine (MDEA) have been successfully used to capture carbon dioxide on a large scale. Despite their proven efficacy in capturing CO2, absorption processes still entail major drawbacks.
The most important problems are related to the corrosive properties of liquid amines, the amine losses incurred during the operation, and, significantly, the energy consumption in the regeneration process. Therefore, in recent years many efforts and significant funding have been focused on the development of alternative processes for CO2 capture, such as cryogenic, adsorption, or membrane-based technologies. Carbonation−calcinaon uses the carbonaon reaction between quicklime (calcium oxide, CaO) and CO2 to produce limestone (calcium carbonate, CaCO3).Calcium carbonate is then introduced in a calcination reactor, where the opposite process is performed. Calcination yields regenerated quicklime and a gas stream enriched in CO2. The main advantages of this technology are the low cost of the initial limestone used and its reactivity toward both CO2 and SO2. Thus, no desulfurization step is needed prior to carbonation−calcinaon. However, the high temperature used during the carbonation (650 °C) and calcination reactions (900 °C) as well as material attrition are a significant economic drawback. The carbonation step is commonly performed with flue gas, in a postcombustion CO2 capture setup. Nevertheless, it can also be applied to precombustion, for example, during coal or biomass gasification (Table 1).
| | | syngas | | oxy-fuel | | flue gas
| | | (precombustion) | | combustion | | (postcombustion)
pressure (atm) | | >5 | | >50 | | 1
temperature (°C) | | >100 <50 <100
| CO2 concentration | | ~35 | | >90 | | 4-14
(vol %)

Table 1: Typical Pressures, Temperatures, and CO2 Concentrations of the Different Gas Streams Used in CCS Technologies

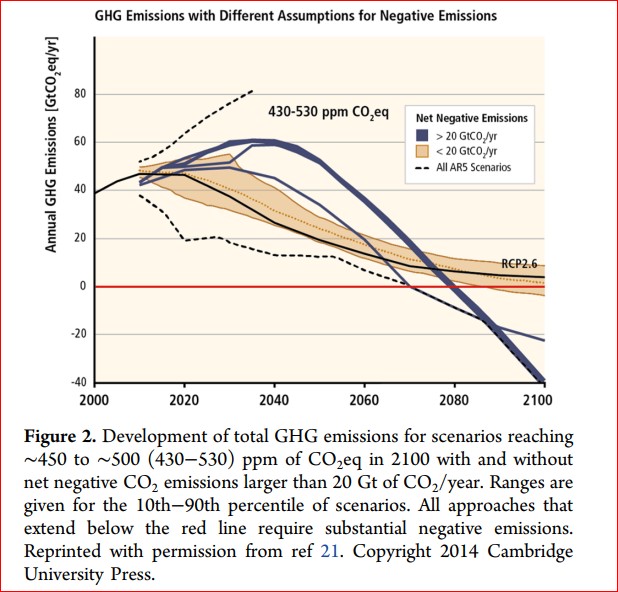
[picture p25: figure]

10

1.3. Reduction of CO2 Emissions vs Negative Carbon Technologies Given the slow realization that the last century of carbon dioxide emissions has significantly impacted the climate, society has continued to use fossil fuels at an ever-expanding rate over the past few decades. Although the IPCC recognized the need for rapid and immediate reductions in fossil fuel use in 1990, the rate of anthropogenic CO2 emissions has continued to expand rapidly, with little slowdown in sight. While the use of noncarbon energy technologies is quickly growing, the growth does not match the pace of a growing global population’s energy demands. As such, there appears to be little probability of a slowing of CO2 emissions, globally, in the near future. In fact, the latest IPCC report from Working Group III suggests that society has reached a point where it is very likely that stabilizing the atmosphere at twice the preindustrial level will require negative CO2 emissions in the later part of this century, as can be seen in Figure 2.

To this end, the recent climate talks in Paris have identified the need for rapid deployment of “negative carbon technologies,” technologies that can remove CO2 from the atmosphere. Additionally, the report from the National Research Council (NRC) on Climate Intervention also concluded that research and development of negative carbon technology is warranted. This is in contrast to the conventional CO2 capture technologies described above, which, even if widely deployed, would only slow the rate of increase of the global atmospheric CO2 concentration.

This Review describes the advances made in the direct extraction of CO2 from ambient air using sorbents, or direct air capture (DAC), as one of the few potential “negative car
technologies. The history of DAC from a climate perspective is first presented, followed by the identification of an array of sorbents and processes that have been examined for their utility in extracting CO2 from the atmosphere. A brief discussion of
DAC is also included. Finally, an overview of the feasibility and cost of DAC processes is presented.
Conclusion: These theories and practices are often interconnected and implemented simultaneously to create a comprehensive
to note that developments in this field continue, and new strategies and policies are emerging frequently.

### Basic block diagram

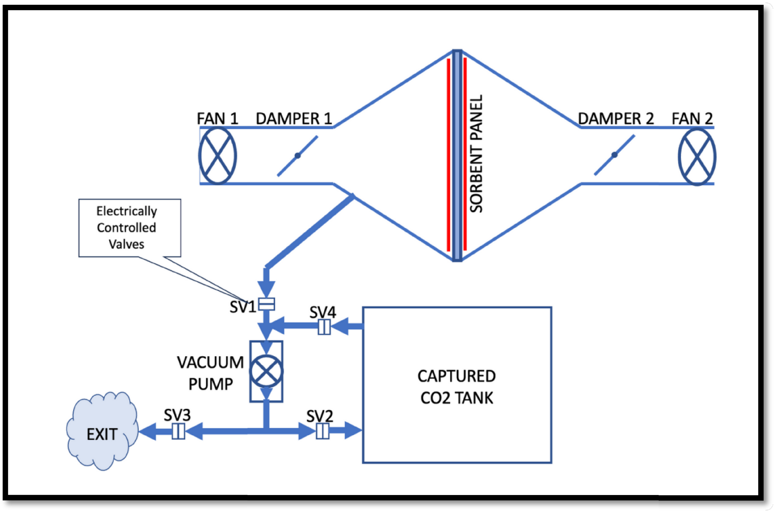
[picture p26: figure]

Figure: Schematic representation of direct air capture of CO2 with Source: Redrawn from David Sandalow et al. (2018).

11

bon”

nonsorbent-based approaches to

These theories and practices are often interconnected and implemented approach to CO2 emissions reduction. It's important

:

utilization and storage

bon”

12

## Objectives

The objective of this project is to design, develop, and implement an innovative Direct Air Capture (DAC) system that addresses the urgent need for scalable and sustainable carbon removal solutions. This project aims to contribute to the mitigation of climate change by achieving the following key objectives:

### 1. Development of an Efficient DAC Technology:

- Design and construct a state-of-the-art DAC system that maximizes CO2 capture efficiency while minimizing energy consumption.
- Investigate and integrate advanced capture materials and methods, such as chemical sorbents, adsorption technologies, and electrochemical approaches, to enhance DAC system performance.

### 2. Scalability and Cost Reduction:

- Engineer the DAC system with scalability in mind, ensuring it can be deployed at a sizeable capacity to have a meaningful impact on CO2 removal.
- Explore innovative engineering and manufacturing processes to reduce the overall cost of DAC technology, making it economically viable for widespread deployment.

### 3. Carbon Utilization and Storage:

- Investigate opportunities for the utilization of captured CO2, such as in the production of carbon-neutral fuels, construction materials, or other value-added products.
- Implement effective and environmentally responsible strategies for the secure and long-term storage of captured CO2, including geologic storage and utilization in carbon-negative applications.

### 4. Environmental Sustainability:

- Conduct a comprehensive life cycle assessment (LCA) to evaluate the environmental footprint of the DAC system, taking into account emissions associated with construction, operation, and decommissioning.
- Develop strategies to minimize water usage, land footprint, and other potential environmental impacts associated with DAC deployment.

13

## Scope of the project

### 1. Direct Air Capture (DAC):

- Scope:
- DAC technology involves capturing CO2 directly from the air using various chemical processes. It is seen as a potential solution for reducing atmospheric carbon dioxide levels.
- The scope of DAC extends to applications where direct removal of CO2 from the atmosphere is necessary to achieve climate targets.
- Challenges:
- High costs have been a significant challenge for DAC technologies. Implementing large-scale DAC facilities requires substantial investment.
- Energy requirements for DAC processes can be considerable, and finding sustainable and low-cost energy sources is crucial.
- Recent Developments:
- Ongoing research and development aim to improve the efficiency and reduce the costs associated with DAC technologies.
- Pilot projects and demonstration plants have been initiated to test and scale up DAC capabilities.

### 2. Carbon Capture and Storage (CCS):

- Scope:
- CCS involves capturing CO2 emissions produced from industrial processes or power generation and storing it underground to prevent it from entering the atmosphere.
- The scope of CCS is broad and includes applications in power plants, industrial facilities, and other large-scale point sources of CO2 emissions.
- Challenges:
- One of the main challenges for CCS is the cost of capturing and storing CO2. Implementation has been hindered by economic considerations and a lack of policy incentives.
- Public acceptance and concerns about the long-term integrity of CO2 storage sites are challenges that need to be addressed.
- Recent Developments:
- Some countries have started to invest in and implement CCS projects as part of their climate change mitigation strategies.
- Advances in technology and increased awareness of the importance of carbon capture have led to the development of new and more efficient capture methods.

14

Integration and Future Outlook:

- Combined Approaches:
- There is growing recognition that a combination of DAC and CCS technologies, along with other mitigation strategies, may be needed to achieve significant reductions in CO2 levels.
- Policy and Funding:
- The future scope of DAC and CCS will likely be influenced by government policies, international agreements, and financial incentives that support the development and deployment of these technologies.
- Technological Advances:
- Ongoing research and innovation are expected to drive improvements in both DAC and CCS technologies, making them more cost-effective and scalable.


Figure: Schematic representation of direct air capture of CO2 with Source: Redrawn from David Sandalow et al. (2018).

## Working:-

### 1. Air Intake and Control:

- Fan 1 pulls in ambient air, and Dampers 1 regulate the airflow, directing it to the sorbent panel

### 2. CO2 Absorption:

- The airflow, now containing CO2, passes through the sorbent panel where a specialized material selectively absorbs the CO2.

15

## Methodology

utilization and storage

Fan 1 pulls in ambient air, and Dampers 1 regulate the airflow, directing it .

The airflow, now containing CO2, passes through the sorbent panel where

16

CxHy + xH2O → xCO + x +

H2 (1)

CxHy +

x
2

O2 → x CO +

y
2
H2 | (2)
CO + H2O → CO2 + H2 | (3)

### 3. CO2 Capture and Routing:

- Fan 2 is activated to guide the CO2-laden air toward the capture tank, controlled by Dampers 2 for optimized airflow.

### 4. CO2 Storage:

- Within the capture tank, CO2 is collected and stored for subsequent processing.

### 5. Vacuum-Assisted CO2 Extraction:

- The vacuum pump creates a low-pressure environment in the capture tank, facilitating the extraction of CO2 from the sorbent material.

### 6. Controlled Operation via Switches:

- The four switches play a vital role in managing the system, coordinating the fans, dampers, and vacuum pump at specific phases to ensure efficient CO2 capture.

In summary, the DAC system utilizes fans, dampers, a sorbent panel, a capture tank, a vacuum pump, and switches to draw in air, absorb CO2, store captured CO2, and facilitate its extraction. This systematic process showcases the potential of DAC in effectively reducing atmospheric CO2 levels, contributing to environmental sustainability.

17
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

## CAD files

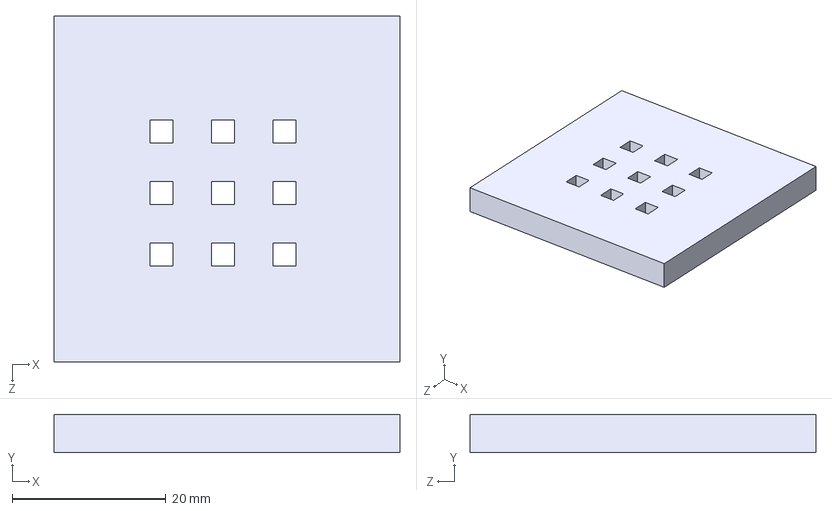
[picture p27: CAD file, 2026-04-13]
Documents/3D Design/sorbent panel.IGS
45.0 x 5.00 x 45.0 mm

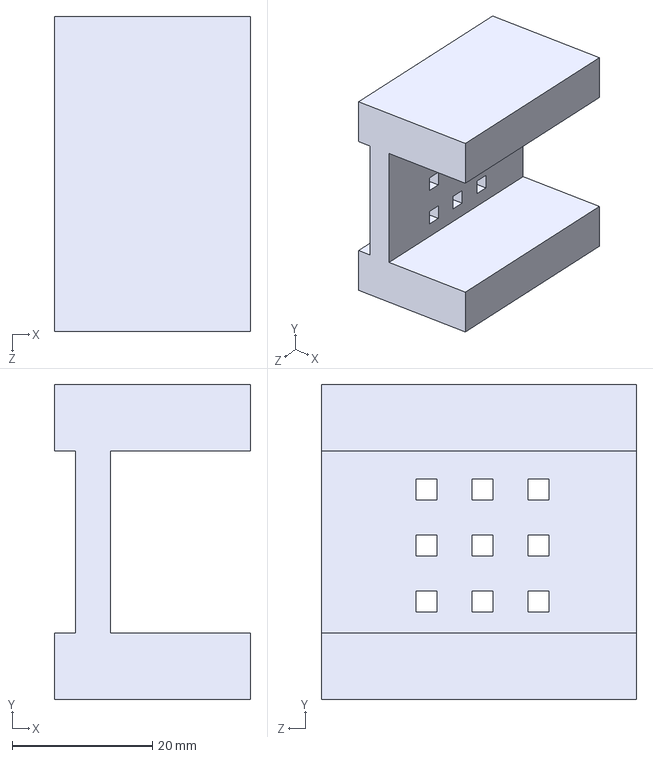
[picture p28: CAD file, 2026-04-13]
Documents/3D Design/I-section of sorbent panel.IGS
28.0 x 45.0 x 45.0 mm

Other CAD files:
Documents/3D Design/100mm.CATPart
Documents/3D Design/150mm.CATPart
Documents/3D Design/Part1.CATPart
Documents/3D Design/left.CATPart
Documents/3D Design/right.CATPart

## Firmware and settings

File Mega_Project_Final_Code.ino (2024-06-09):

#include <LiquidCrystal.h>
const int rs = 12, en = 11, d4 = 5, d5 = 4, d6 = 3, d7 = 2;
LiquidCrystal lcd(rs, en, d4, d5, d6, d7);


  //Analog Input Declaration  
  int ps1 = A0;
  int tmp = A1;
  int co2 = A2;
  int ps2 = A3;

  int ps1_val = 0;
  int tmp_val = 0;
  int ps2_val = 0;
  int co2_val = 0;

  //Digital Output Declaration
  int fan = 23;
  int SV1 = 27;
  int heater = 29;
  int SV2 = 31;
  int SV3 = 35;
  int SV4 = 39;
  int SV5 = 43;
  int vacc = 47;



void setup() 
{
  // put your setup code here, to run once:
  lcd.begin(16, 2);
  Serial.begin(9600);

  // Declaring sensors as input 
  pinMode(ps1, INPUT);
  pinMode(tmp, INPUT);
  pinMode(co2, INPUT);
  pinMode(ps2, INPUT);


  //Declaring actuators and heater as output
  pinMode(fan, OUTPUT);
  pinMode(SV1, OUTPUT);
  pinMode(heater, OUTPUT);
  pinMode(SV2, OUTPUT);
  pinMode(SV3, OUTPUT);
  pinMode(SV4, OUTPUT);
  pinMode(SV5, OUTPUT);
  pinMode(vacc, OUTPUT);

}

void loop() 
{
  // put your main code here, to run repeatedly:

  // int ps1 = analogRead(A0);
  // int ps1_val = (ps1, 0, 1023, 1, 150);

  // int tmp = analogRead(A1);
  // int tmp_val = (tmp, 900, 450, -200, 258);

  // int co2 = analogRead(A2);
  // int co2_val = (co2, 0, 1023, 400, 10000);

  // int ps2 = analogRead(A3);
  // int ps2_val = (ps2, 0, 1023, 1, 150);

  dis();




  Air_Flow();
  delay(3000);
  vacuum();
  delay(3000);
  heat();
  delay(3000);
  store();
  delay(3000);
  
}

void Air_Flow()
{
  Serial.println(" Air Flow is executing");
  
  int i;

  digitalWrite(SV1, LOW);
  digitalWrite(SV2, LOW);
  digitalWrite(SV3, LOW);
  digitalWrite(SV4, HIGH);
  digitalWrite(SV5, HIGH);
  digitalWrite(fan, LOW);
  digitalWrite(vacc, HIGH);
  digitalWrite(heater, LOW);  
  
  dis();
  //delay(30*60*1000);  //DELAY(total minutes*one min*one sec)
  //delay(3*60*1000);  // delay of 3 min for demonstration
  //delay(1*60*1000);  // delay of 1 min for demonstration
  //delay(5000);// i.e 5 sec delay

  for(i=0;i<=20;i++)
  {
    delay(1000);
    dis();

  }
  //vacuum();
}

void vacuum()
{
  Serial.println(" Vacuum is executing");
  digitalWrite(SV1, HIGH); // Close SV1
  digitalWrite(SV3, HIGH); // Close SV3
  digitalWrite(SV4, HIGH); // Close SV3
  digitalWrite(fan, HIGH); // Switch off fan
  digitalWrite(heater, LOW); // Heater OFF
  digitalWrite(SV2, LOW); // Open SV2
  digitalWrite(SV5, LOW); // Open SV5
  digitalWrite(vacc, LOW); // Compressor ON

  dis();

  delay(3000);

  ps1_check();

  dis();

  delay(3000);
}

void heat()
{
  digitalWrite(SV1, HIGH); // Close SV1
  digitalWrite(SV3, HIGH); // Close SV3
  digitalWrite(SV4, HIGH); // Close SV3
  digitalWrite(fan, LOW); // Switch ON fan
  digitalWrite(heater, HIGH); // Heater ON
  digitalWrite(SV2, HIGH); // Close SV2
  digitalWrite(SV5, HIGH); // Close SV5
  digitalWrite(vacc, HIGH); // Compressor OFF

  dis();

  delay(3000);

  temp_check();

  dis();

  delay(3000);
}

void store()
{
  int ps_final;
  digitalWrite(heater, LOW);

  ps_final=ps1-14+ps2;

  dis();

  delay(3000);

  ps2_check();

  dis();

  delay(3000);
}

void ps1_check()
{
  int ps1_val;
  dis();

  if(ps1_val>14)
  {
    dis();

    delay(3000);
    do
    {
      vacuum();
      dis();
    }
    while(ps1>14);
  }
  else
  {
    dis();

    delay(3000);
    Serial.println(" Vacuum Created ");
    heat();
  }
}

void temp_check()
{ 
  int i, tmp_val;
  for(i=0;i<3;i++)
  { 
    do 
    {
     digitalWrite(heater, HIGH);
     
     dis();

     delay(3000);

    }
    while(tmp_val>=640);

    if(tmp_val>=640)
    {
      do
      {
       digitalWrite(heater, LOW);
       digitalWrite(fan, LOW);
       
       dis();

      
      }
      while(tmp_val>640);
    }
  }
}

void ps2_check()
{
  int ps_final;
  if(ps1>14)
  {
    do
    {
      digitalWrite(SV2, LOW);
      digitalWrite(SV4, LOW);
      digitalWrite(fan, HIGH);
      digitalWrite(vacc, LOW);
      digitalWrite(SV1, HIGH);
      digitalWrite(SV3, HIGH);
      digitalWrite(SV5, HIGH);
      digitalWrite(heater, LOW);

      dis();

      delay(3000);
    }
    while(ps2!=ps_final && ps_final<100 && ps1_val>14);
  }
  else
  {
    dis();

    delay(3000);

    Serial.print(" Chamber empty");
  }
}

void dis()
{
  // int ps1_val, tmp_val, co2_val, ps2_val;
  

  ps1_val = analogRead(ps1);
  //ps1_val = map(ps1_val, 0, 1023, 0, 150);
  lcd.setCursor(0, 0); 
  lcd.print("PS1=");
  lcd.print(ps1_val); // top left
  Serial.println(" Pressure1 is ");
  Serial.println(ps1_val);

  Serial.println(" Temp is ");
  Serial.println(tmp_val);
  tmp_val = analogRead(tmp);
  //int tmp_val = map(tmp, 900, 450, -200, 258);
  lcd.setCursor(8, 0);
  lcd.print("TMP="); // top right
  lcd.print(tmp_val);


  Serial.println(" Pressure2 is ");
  Serial.println(ps2_val);
  ps2_val = analogRead(ps2);
  //int ps2_val = map(ps2, 0, 1023, 1, 150);
  lcd.setCursor(0, 1);
  lcd.print("PS2="); // bottom left
  lcd.print(ps2_val);


  Serial.println(" CO2 concentration is ");
  Serial.println(co2_val);
  co2_val = analogRead(co2);
  //int co2_val = map(co2, 0, 1023, 400, 10000);
  lcd.setCursor(8, 1);
  lcd.print("CO2=");
  lcd.print(co2_val);


}
